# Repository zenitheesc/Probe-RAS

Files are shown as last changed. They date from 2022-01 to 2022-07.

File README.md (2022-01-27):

<h1 align="center" style="color:white; background-color:black">Probe-RAS</h1>
<h4 align="center"> Telecommunication board for the Zenith's Stack architecture.</h4>

<p align="center">
	<a href="http://zenith.eesc.usp.br/">
    
    </a>
    <a href="https://eesc.usp.br/">
    
    </a>
    <a href="https://github.com/zenitheesc/Probe-RAS/blob/main/LICENSE">
    
    </a>
    <a href="https://github.com/zenitheesc/Probe-RAS/issues">
    
    </a>
    <a href="https://github.com/zenitheesc/Probe-RAS/commits/main">
    
    </a>
    <a href="https://github.com/zenitheesc/Probe-RAS/graphs/contributors">
    
    </a>
    <a href="https://github.com/zenitheesc/Probe-RAS/commits/main">
    
    </a>
    <a href="https://github.com/zenitheesc/Probe-RAS/issues">
    
    </a>
    <a href="https://github.com/zenitheesc/Probe-RAS/pulls">
    
    </a>
</p>

<p align="center">
    <a href="#environment-and-tools">Environment and Tools</a> •
    <a href="#Z-Hub">Z-Hub</a> •
    <a href="#Block-Diagram">Block Diagram</a> •
    <a href="#Schematic">Schematic</a> • 
    <a href="#Board">Board</a>
</p>

## Environment and tools

This board was designed using KiCad 5.1.10.

## Block Diagram

<p align = "center">
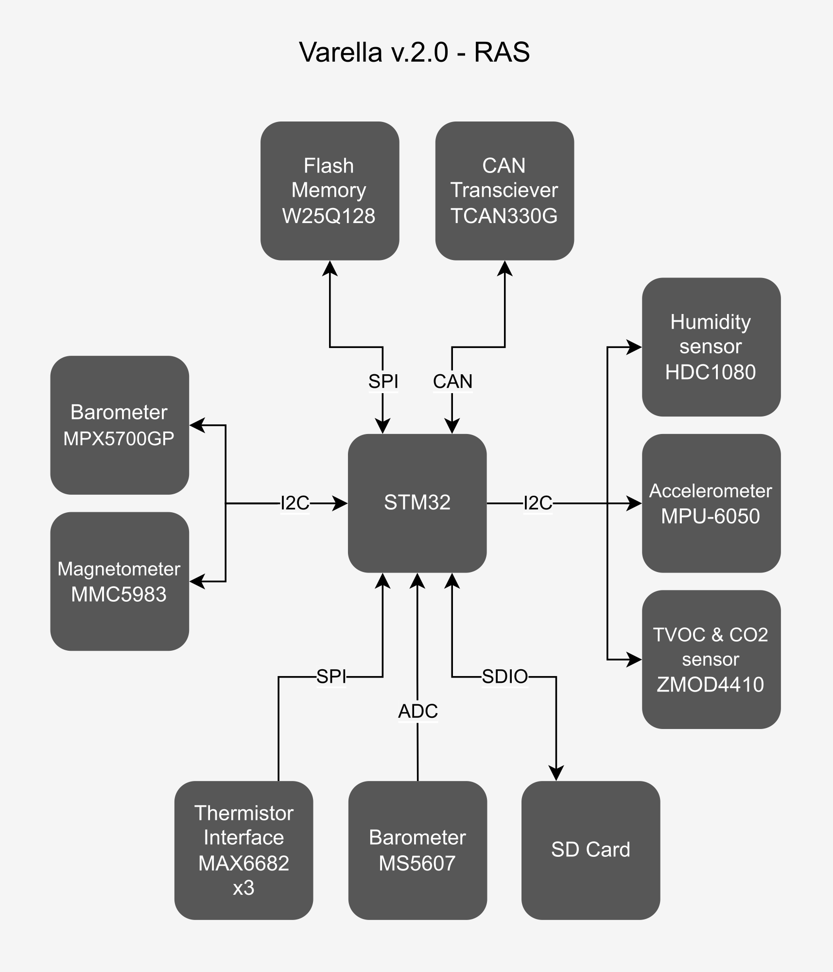
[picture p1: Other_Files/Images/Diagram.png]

</p>

## Z-Hub

This board contains a Stack Connector, with the 2021 Z-Hub pinout.

<table align = "center">
  <thead>
    <tr>
      <th colspan=2>   Z-Hub 2021   </th>
    </tr>
  </thead>
  <tbody>
    <tr>
      <td>GND</td>
      <td>GND</td>
    </tr>
    <tr>
      <td>GND</td>
      <td>GND</td>
    </tr>
    <tr>
      <td>BAT+</td>
      <td>BAT+</td>
    </tr>
    <tr>
      <td>SOl+</td>
      <td>SOl-</td>
    </tr>
    <tr>
      <td>5V</td>
      <td>5V</td>
    </tr>
    <tr>
      <td>3V3</td>
      <td>3V3</td>
    </tr>
    <tr>
      <td>MISO1</td>
      <td>MOSI1</td>
    </tr>
    <tr>
      <td>SCK1</td>
      <td>CAN_H</td>
    </tr>
    <tr>
      <td>SDA </td>
      <td>CAN_L</td>
    </tr>
    <tr>
      <td>SCL</td>
      <td>CE02</td>
    </tr>
    <tr>
      <td>CE11</td>
      <td>CE12</td>
    </tr>
    <tr>
      <td>SDA1</td>
      <td>SCL1</td>
    </tr>
    <tr>
      <td>SDA2</td>
      <td>SCL2</td>
    </tr>
    <tr>
      <td>TX1</td>
      <td>RX1</td>
    </tr>
    <tr>
      <td>TX2</td>
      <td>RX2</td>
    </tr>
    <tr>
      <td>DIG1</td>
      <td>DIG6</td>
    </tr>
    <tr>
      <td>ALRT1</td>
      <td>/CHRG</td>
    </tr>
    <tr>
      <td>PWM</td>
      <td>DIG8</td>
    </tr>
    <tr>
      <td>/FAULT</td>
      <td>DIG9</td>
    </tr>
    <tr>
      <td>DIG5</td>
      <td>DIG10</td>
    </tr>
  </tbody>
</table>

## Schematic

The design was separated in hierarchical sheets to accommodate all components in an orderly way.

The first page contains the STM32L476 with all its accompanying circuits; crystals, debugging LED, Boot solder jumper, decoupling capacitors and reset button. On the same page you find the stack connector along with a programming and debugging connector, as well as the I2C pull-ups for all I2C lines. 

<p align = "center">
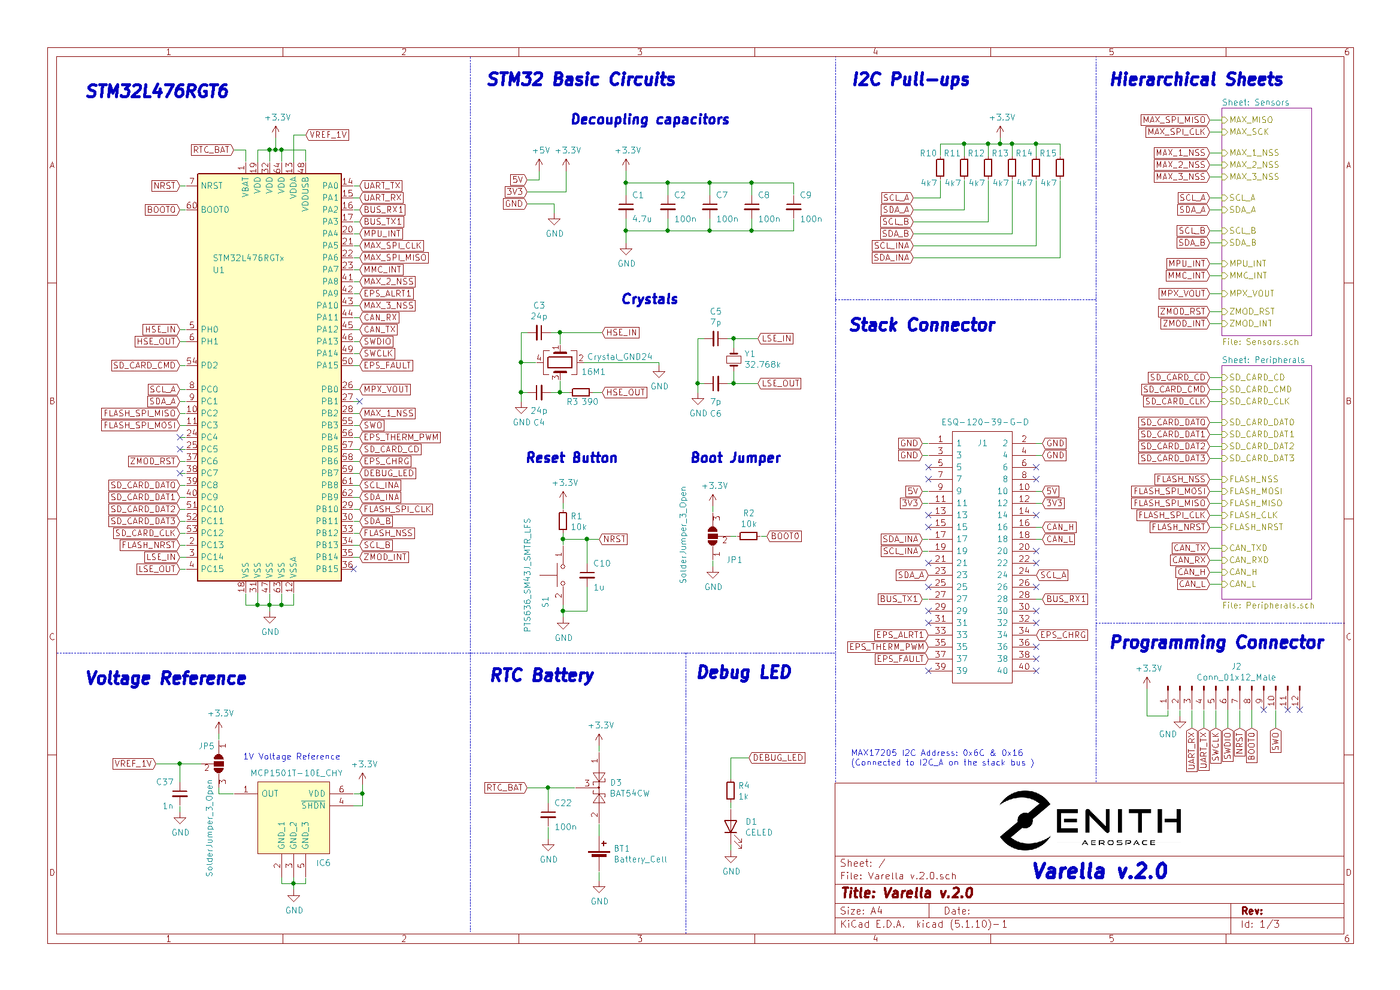
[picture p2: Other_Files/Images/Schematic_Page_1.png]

</p>

The second page contains the basic peripherals, such as the CAN transceiver, the 128 Mb flash memory and the SD card.

<p align = "center">
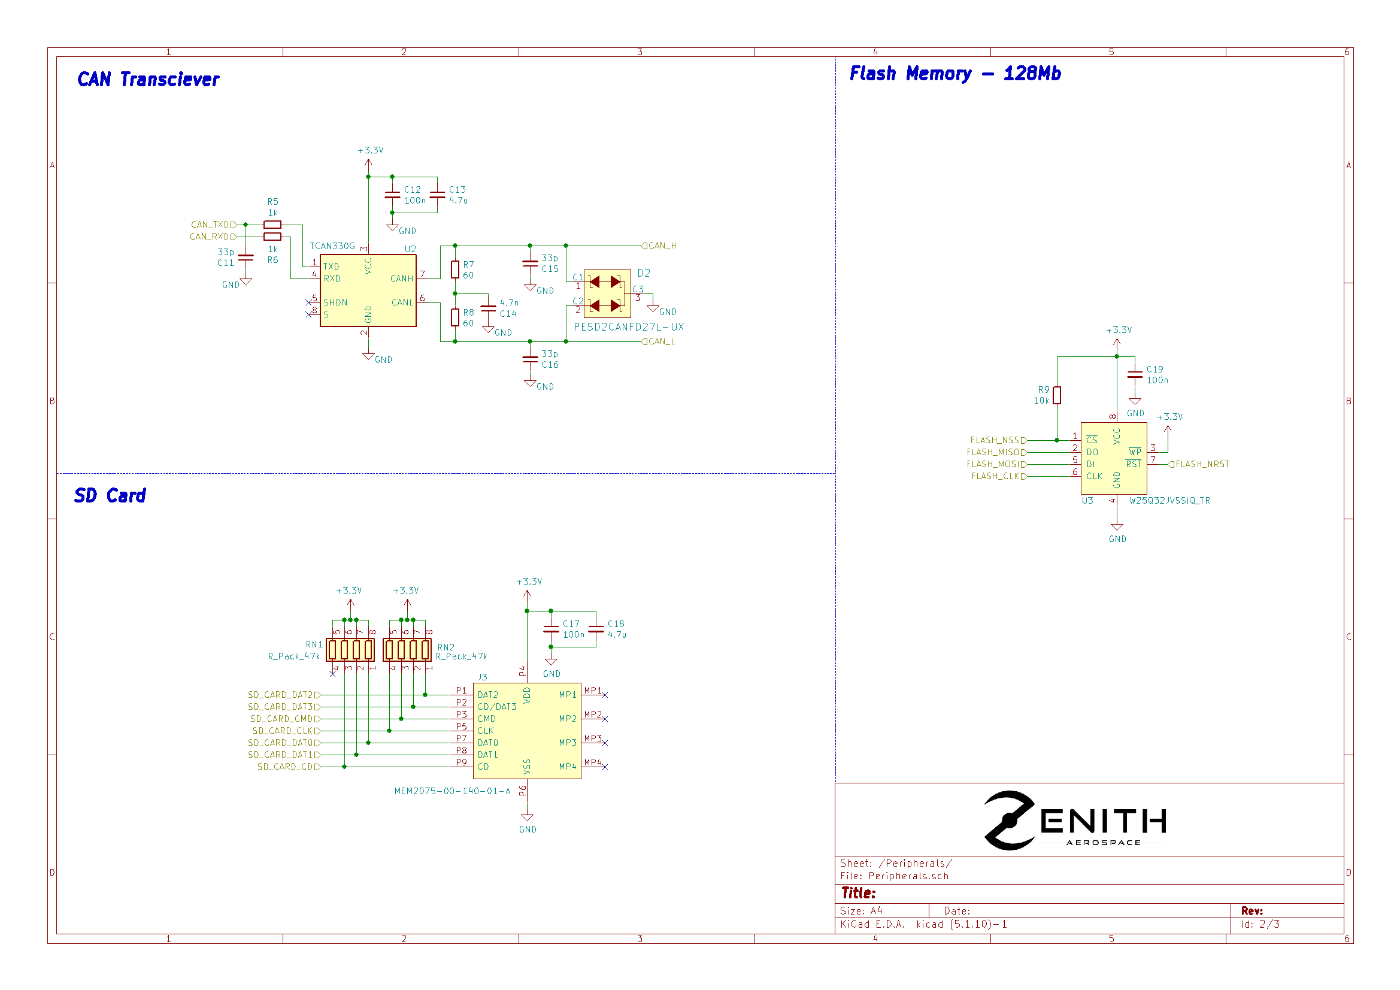
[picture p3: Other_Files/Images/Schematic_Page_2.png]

</p>

The last page contains all the sensors implemented on this board. The I2C ones are divided in two lines, the first one being I2CA, which covers the MS5607 Barometer, the HDC-1080 Humidity sensor and the ZMOD4410 CO2 and air quality sensor. The second I2C line is I2CB, focused on the attitude of the probe, covering the MPU-6050 Accelerometer and the MMC5983 Magnetometer.
This page also contains the Thermistor Interfaces, connected to the STM32 via SPI, but note that these components only use the MISO connection of the SPI line.
The last component that this page contains is the MPX5071GP, which outputs pressure data via a 5V line, read via an ADC by the STM32.

<p align = "center">
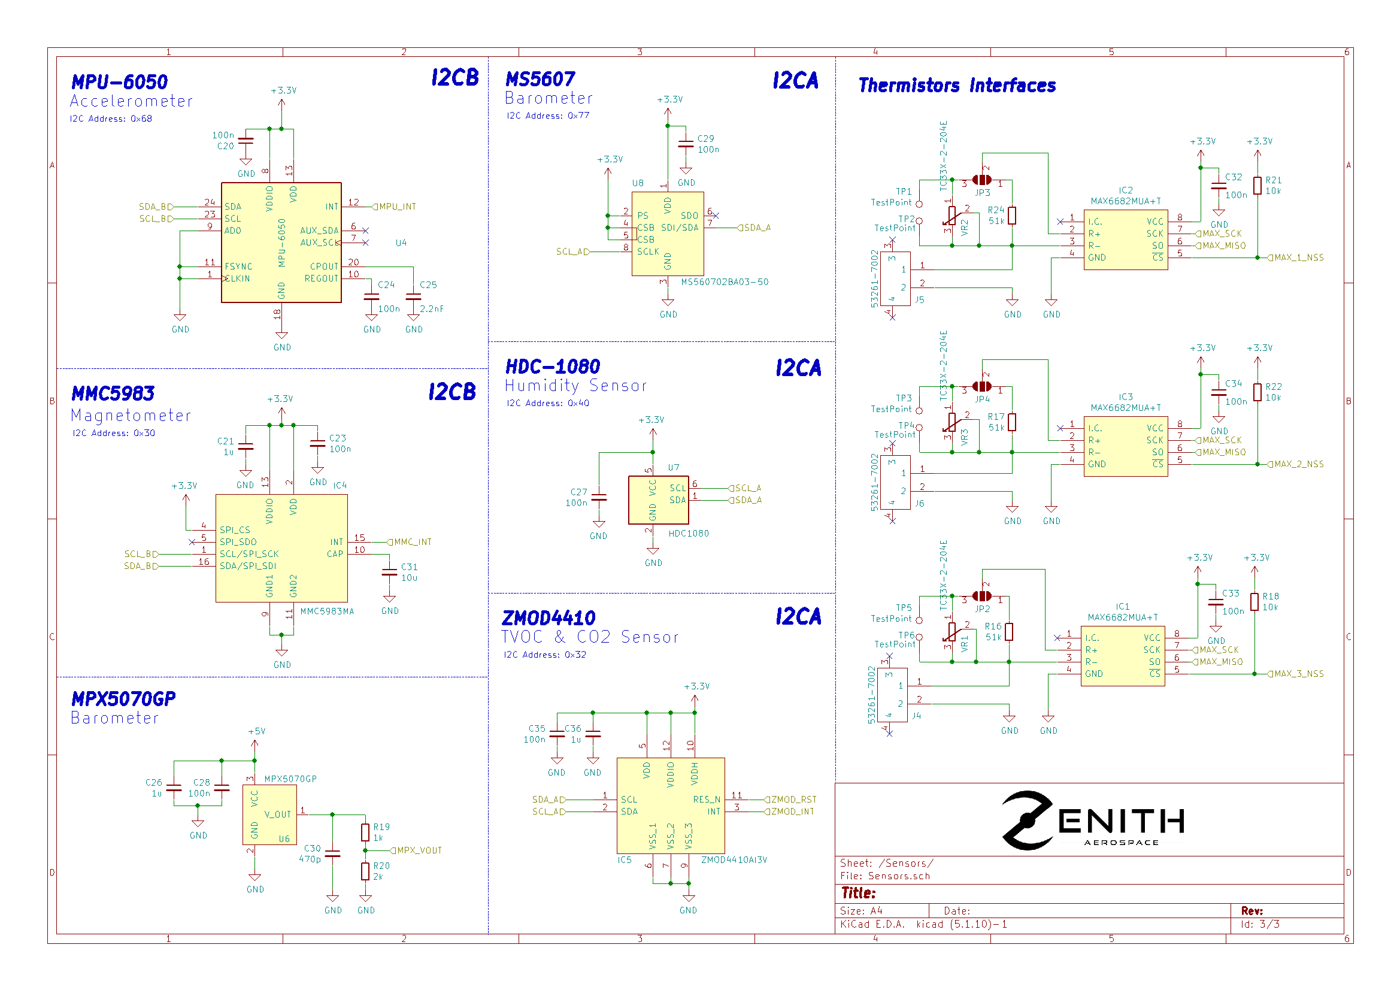
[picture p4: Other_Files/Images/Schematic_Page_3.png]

</p>

## Board

<p align = "center">
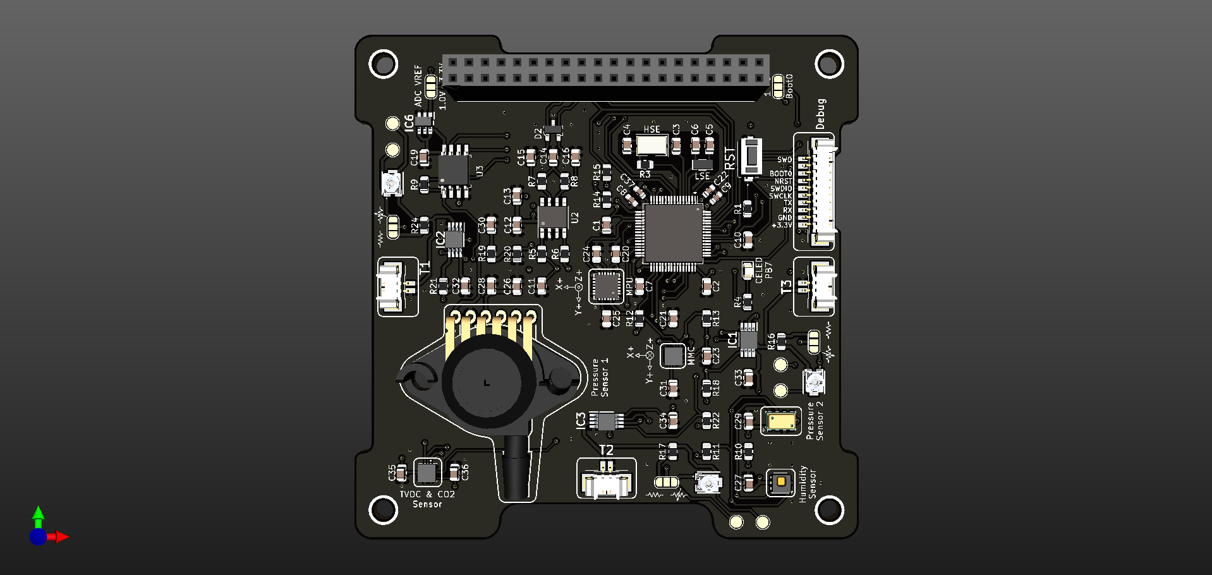
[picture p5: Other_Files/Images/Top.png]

</p>

<p align = "center">
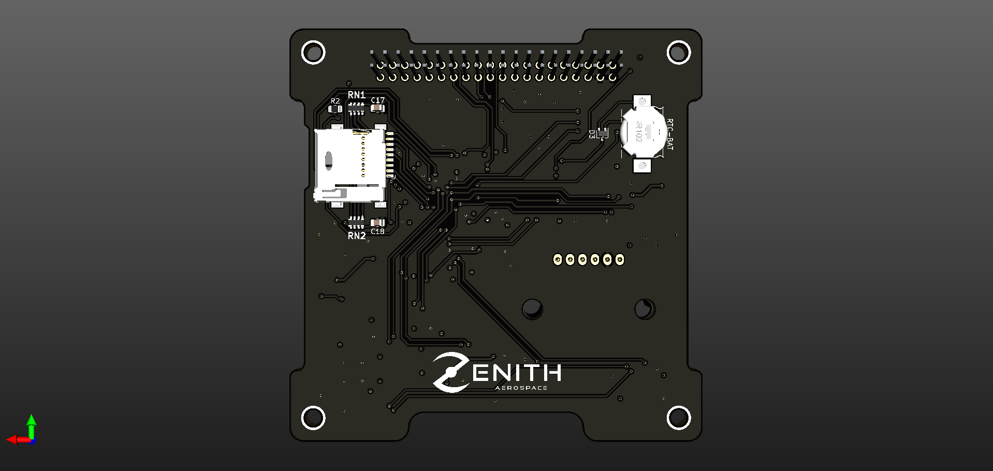
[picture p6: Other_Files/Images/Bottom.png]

</p>

<p align = "center">
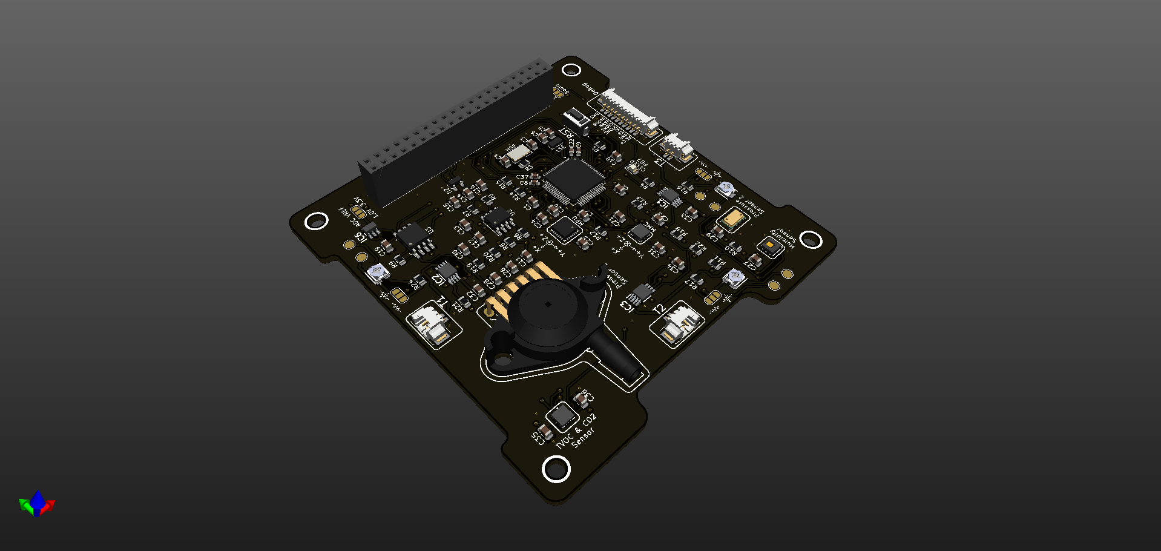
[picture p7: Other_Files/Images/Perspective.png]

</p>

---

<p align="center">
    <a href="http://zenith.eesc.usp.br">
    
    </a> 
    <a href="https://www.facebook.com/zenitheesc">
    
    </a> 
    <a href="https://www.instagram.com/zenith_eesc/">
    
    </a>

</p>
<p align = "center">
<a href="zenith.eesc@gmail.com">zenith.eesc@gmail.com</a>
</p>

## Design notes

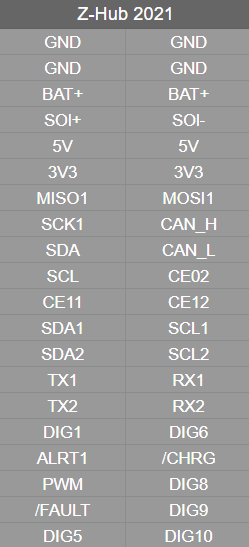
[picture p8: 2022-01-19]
Other_Files/Images/Z-Hub.png

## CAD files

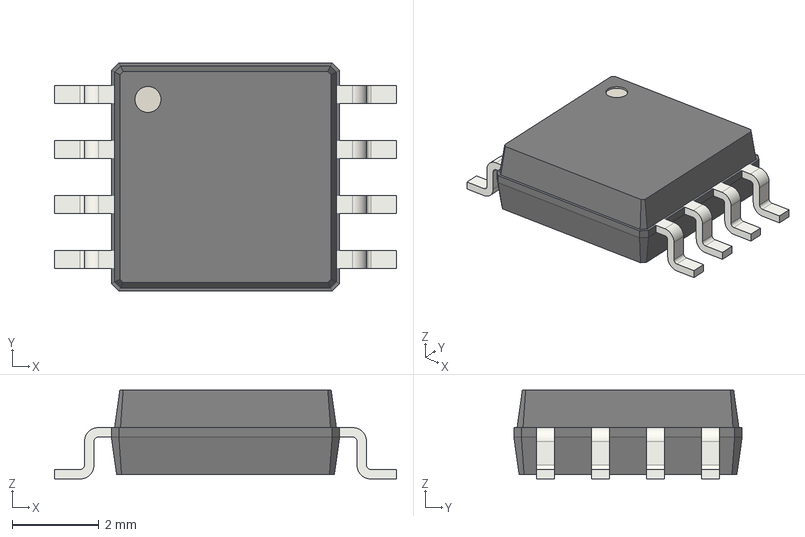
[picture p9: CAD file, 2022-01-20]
KiCad_Files/shapes3D/SOIC-8_5.275x5.275mm_P1.27mm.step
7.90 x 5.28 x 2.06 mm

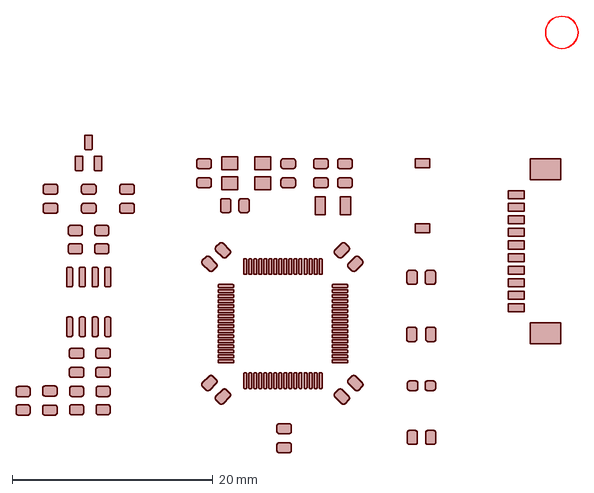
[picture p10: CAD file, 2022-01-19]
KiCad_Files/TopLayerComponents.dxf
55.9 x 43.4 mm

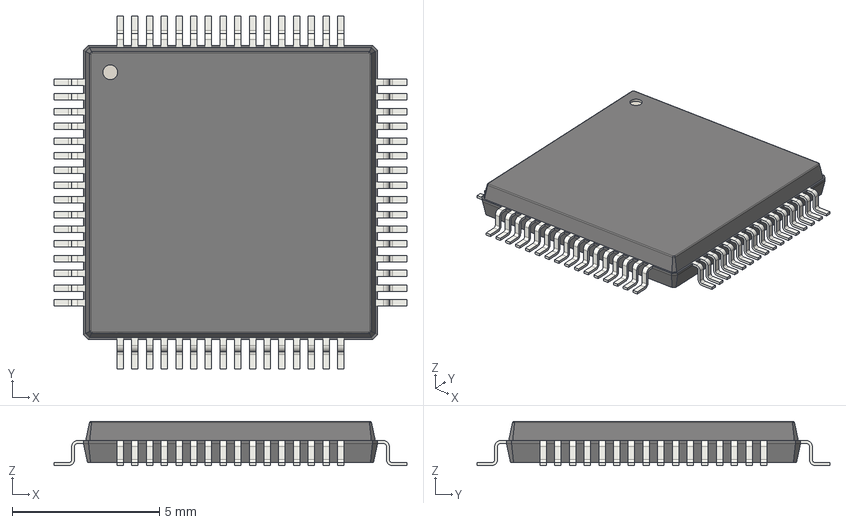
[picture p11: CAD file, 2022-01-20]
KiCad_Files/shapes3D/LQFP-64_10x10mm_P0.5mm.step
12.0 x 12.0 x 1.50 mm

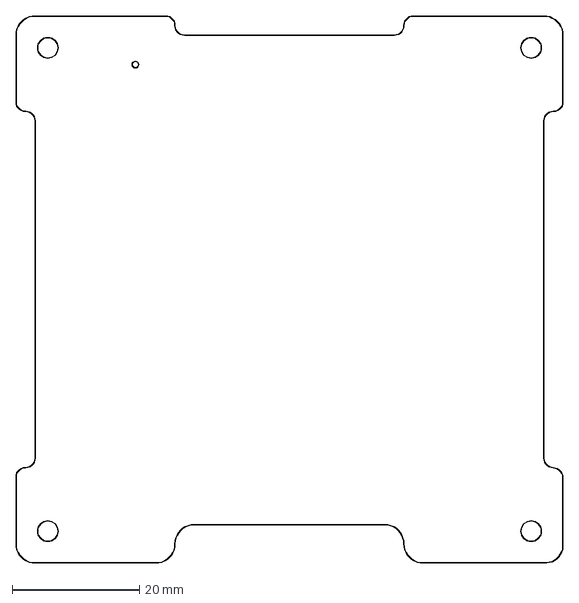
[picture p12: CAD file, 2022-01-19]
KiCad_Files/Stack Model.dxf
86.0 x 86.0 mm

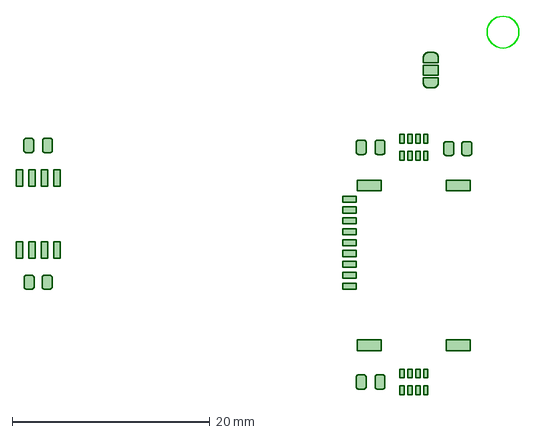
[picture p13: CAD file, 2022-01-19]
KiCad_Files/BottomLayerComponents.dxf
50.9 x 38.3 mm

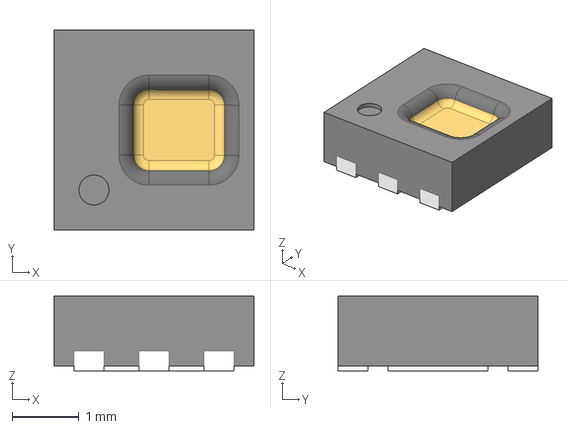
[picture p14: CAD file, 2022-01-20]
KiCad_Files/shapes3D/HDC-1080.step
3.00 x 3.00 x 1.12 mm

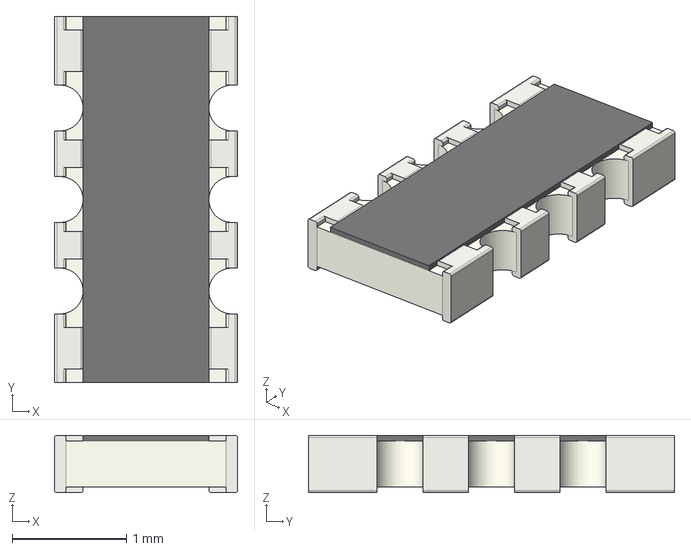
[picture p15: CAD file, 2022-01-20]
KiCad_Files/shapes3D/R_Array_Convex_4x0603.step
1.60 x 3.20 x 0.5 mm

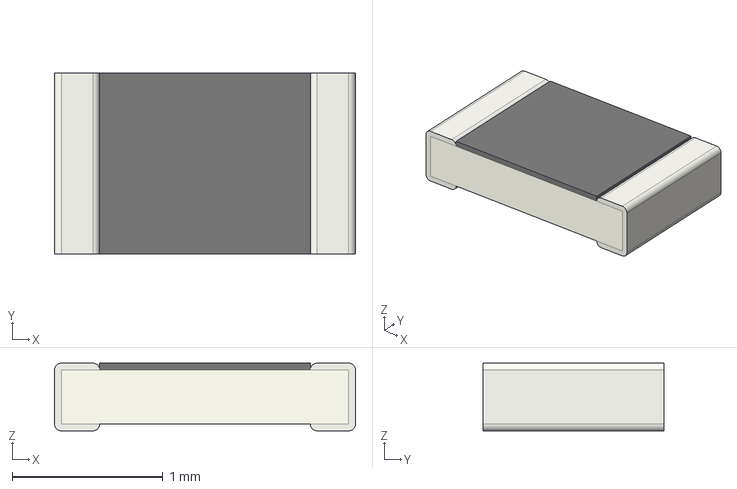
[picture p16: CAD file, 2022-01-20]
KiCad_Files/shapes3D/R_0805_2012Metric.step
2.00 x 1.20 x 0.45 mm

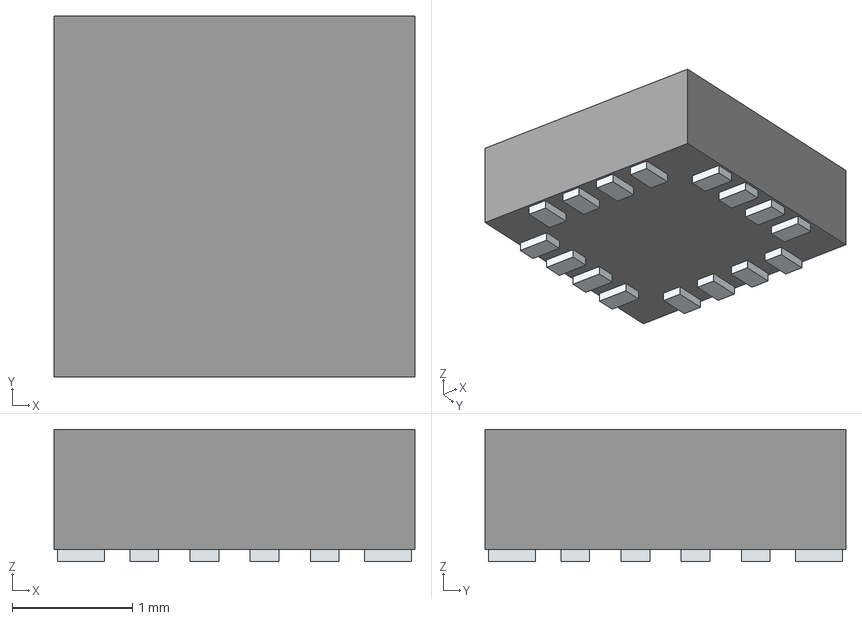
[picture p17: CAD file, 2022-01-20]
KiCad_Files/shapes3D/MMC5983MA.stp
3.00 x 3.00 x 1.10 mm
Pins

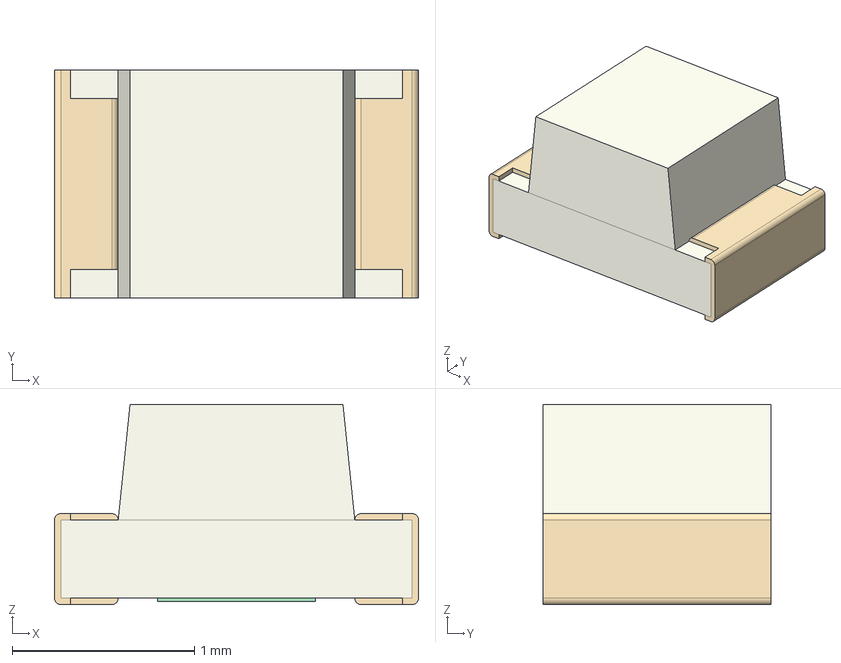
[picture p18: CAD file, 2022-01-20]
KiCad_Files/shapes3D/LED_0805_2012Metric.step
2.00 x 1.25 x 1.10 mm

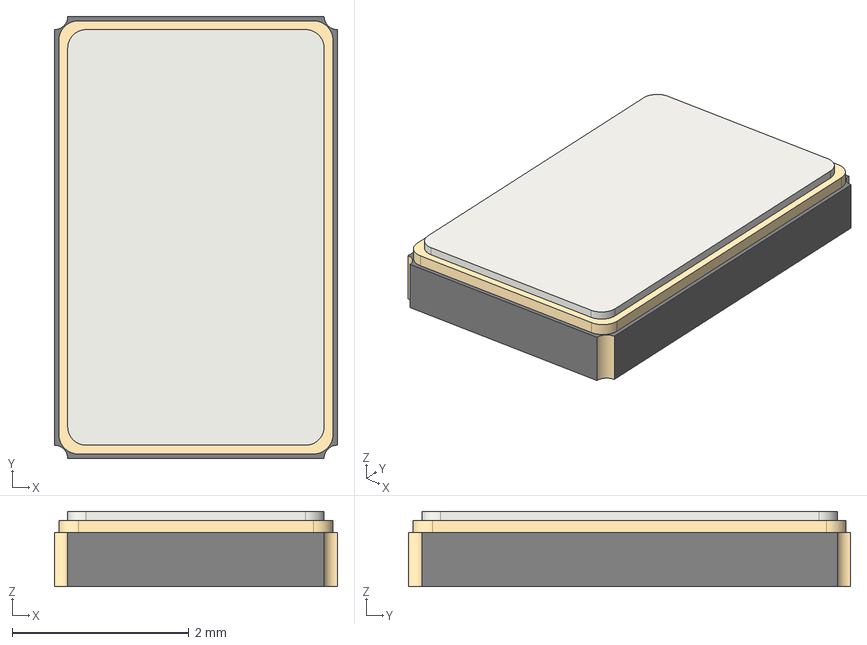
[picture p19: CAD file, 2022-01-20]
KiCad_Files/shapes3D/Crystal_SMD_4Pin_5x3.2mm.step
3.20 x 5.00 x 0.85 mm

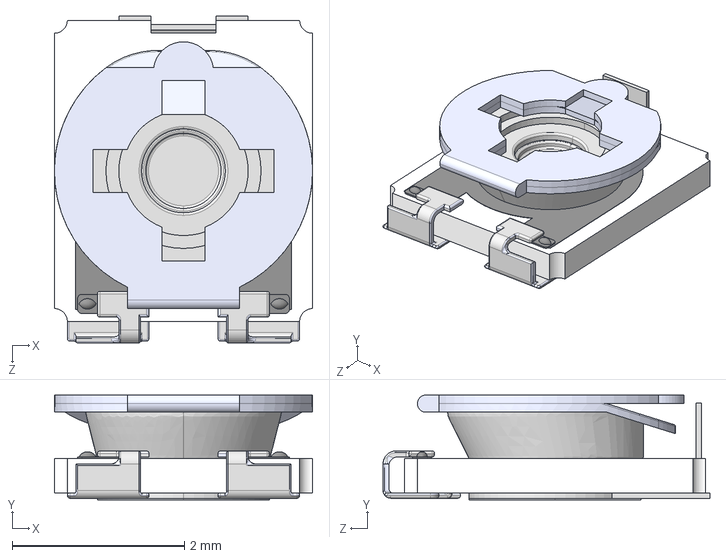
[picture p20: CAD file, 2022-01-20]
KiCad_Files/shapes3D/TC33X-2-204E.stp
3.00 x 1.22 x 3.80 mm

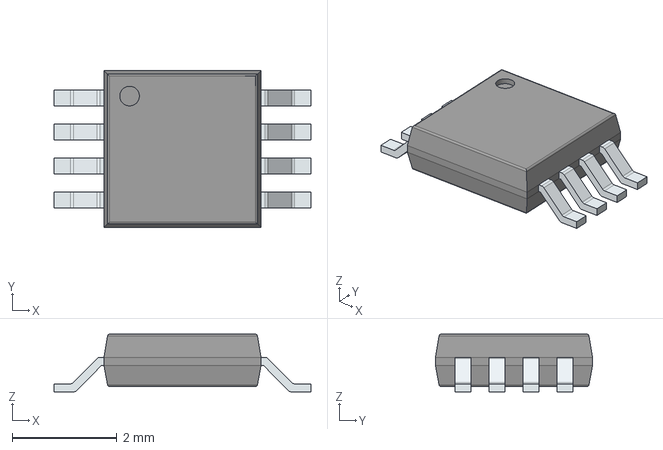
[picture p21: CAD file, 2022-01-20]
KiCad_Files/shapes3D/MAX6682MUA+T.stp
4.91 x 3.00 x 1.10 mm
PinsArrayLR

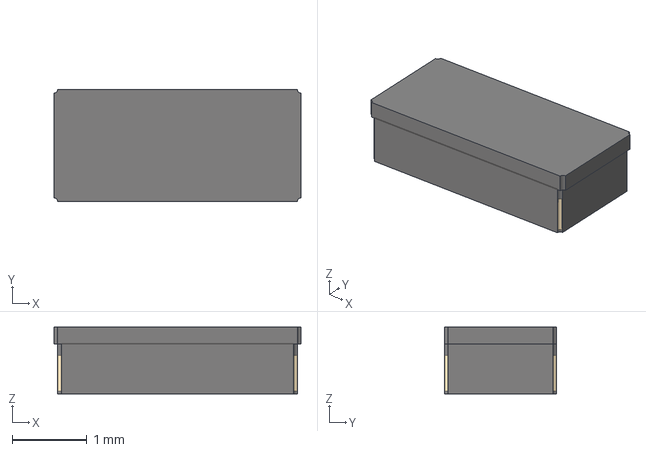
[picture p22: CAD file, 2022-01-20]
KiCad_Files/shapes3D/Crystal_SMD_MicroCrystal_CC7V-T1A-2Pin_3.2x1.5mm.step
3.30 x 1.50 x 0.89 mm

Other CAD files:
KiCad_Files/shapes3D/SOT-23.step
KiCad_Files/shapes3D/C_0805_2012Metric.step
KiCad_Files/shapes3D/User Library-MPX5100GP.step
KiCad_Files/shapes3D/QFN-24-1EP_4x4mm_P0.5mm_EP2.7x2.6mm.step
KiCad_Files/shapes3D/532610271 recolored.step
KiCad_Files/shapes3D/532611071 recolored.step
KiCad_Files/shapes3D/M20-6102045.stp
KiCad_Files/shapes3D/MEM2075-00-140-01-A.stp
KiCad_Files/shapes3D/MS560702BA03-50.step
KiCad_Files/shapes3D/PTS636_SM43J_SMTR_LFS.stp
KiCad_Files/shapes3D/SOIC-8_3.9x4.9mm_P1.27mm.step
KiCad_Files/shapes3D/ZMOD4410AI3V.stp

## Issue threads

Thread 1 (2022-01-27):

Cobertura útil do

leocelente, 2022-01-27:
A expectativa é que a sonda inicie em: [0...30] ± 1 km
Segundo o [modelo atmosférico da NASA](https://www.grc.nasa.gov/WWW/K-12/airplane/atmosmet.html), podemos calcular a pressão em função da altitude:

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

Que são 12hPa

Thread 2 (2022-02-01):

Mecanismo de Configuração

leocelente, 2022-02-01:
# Configuração
## Especificação

Dada uma lista de configurações, construir funções para gerenciar 64-bits de configuração do sistema.
### Tipos
```c
typedef enum { X, Y ... } config_names_t;
typedef enum { CONFIG0, CONFIG1} X_config_t;
//...
typedef struct {
    X_config_t X : 1; // configuração com 2 opções (cabe em 1 bit)
    Y_config_t Y : 3;
    // ...
} config_values_t;

typedef union {
    config_values_t values;
    uint8_t raw[8];
} config_reg_t;
```
### Funções
As configurações variam entre cada sistema, mas ambos são 8 bytes (64-bits). Para conveniência do resto do sistema, deve ser criada também algumas funções para manipular.
```c
/**
   Configura um valor
*/
int config_set_value(config_reg_t *reg, config_names_t config, int value);
int config_reset(config_reg_t *reg);
int config_init(config_reg_t *reg);
int config_set_raw(config_reg_t *reg, uint8_t const *data);
int config_get_value(config_reg_t *reg, config_names_t config);
int config_get_raw(config_reg_t *reg, uint8_t *data);
```

O uso de ints nos argumentos é porque qualquer `enum` é por baixo dos panos um ´int`, então qualquer um dos tipos de configuração pode ser passado. Não tenho certeza se essa é a melhor forma de implementar, se pensar em alguma coisa
sinta-se a vontade.

As funções terminando em `_value` se aplicam a apenas um dos valores, enquanto as que terminam em `_raw`, mudam todos de uma vez.

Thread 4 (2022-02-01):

Mecanismo de Armazenamento

leocelente, 2022-02-01:
Implementar as structs e funções para escrever os dados da RAS e CDH
```c
typedef struct {
  float altiude ;
  uint8_t tempo;
  // ...
} dados_t;

union {
   dados_t valores;
   uint8_t bytes[sizeof(dados_t)];
} pacote_t;

int write_flash(pacote_t pacote){
   // escreve num txt os bytes
}

int write_sdcard(pacote_t pacote){
   // escreve num txt os valores em string (csv)
}
```

## Resultado Esperado
Ter um arquivo txt com o CSV dos dados  como iriam para o cartão SD.  E outro arquivo `.bin` ou `.txt` com os bytes em string

leocelente, 2022-02-01:
lembramos que tem dois tipos de pacote para RAS, que serão armazenados de forma independete o geral e da IMU (grupo1 e grupo2)

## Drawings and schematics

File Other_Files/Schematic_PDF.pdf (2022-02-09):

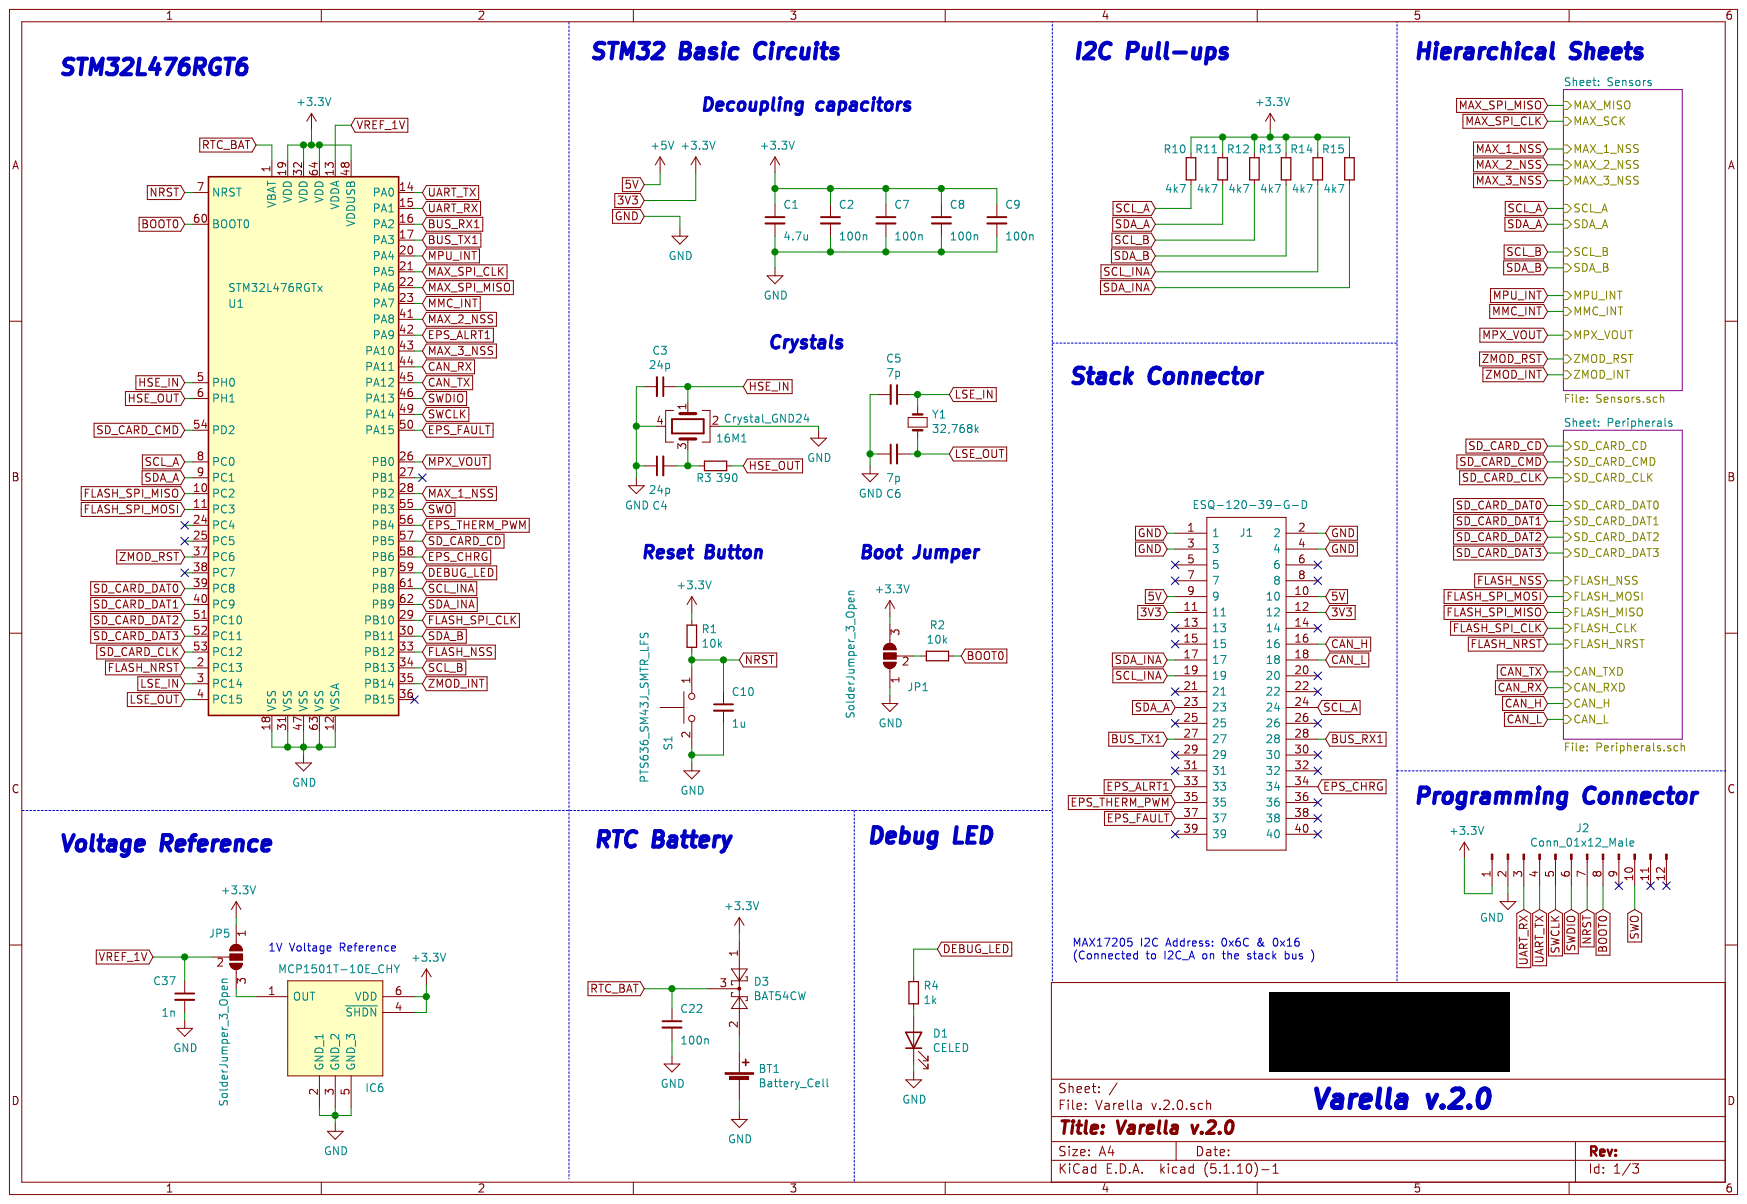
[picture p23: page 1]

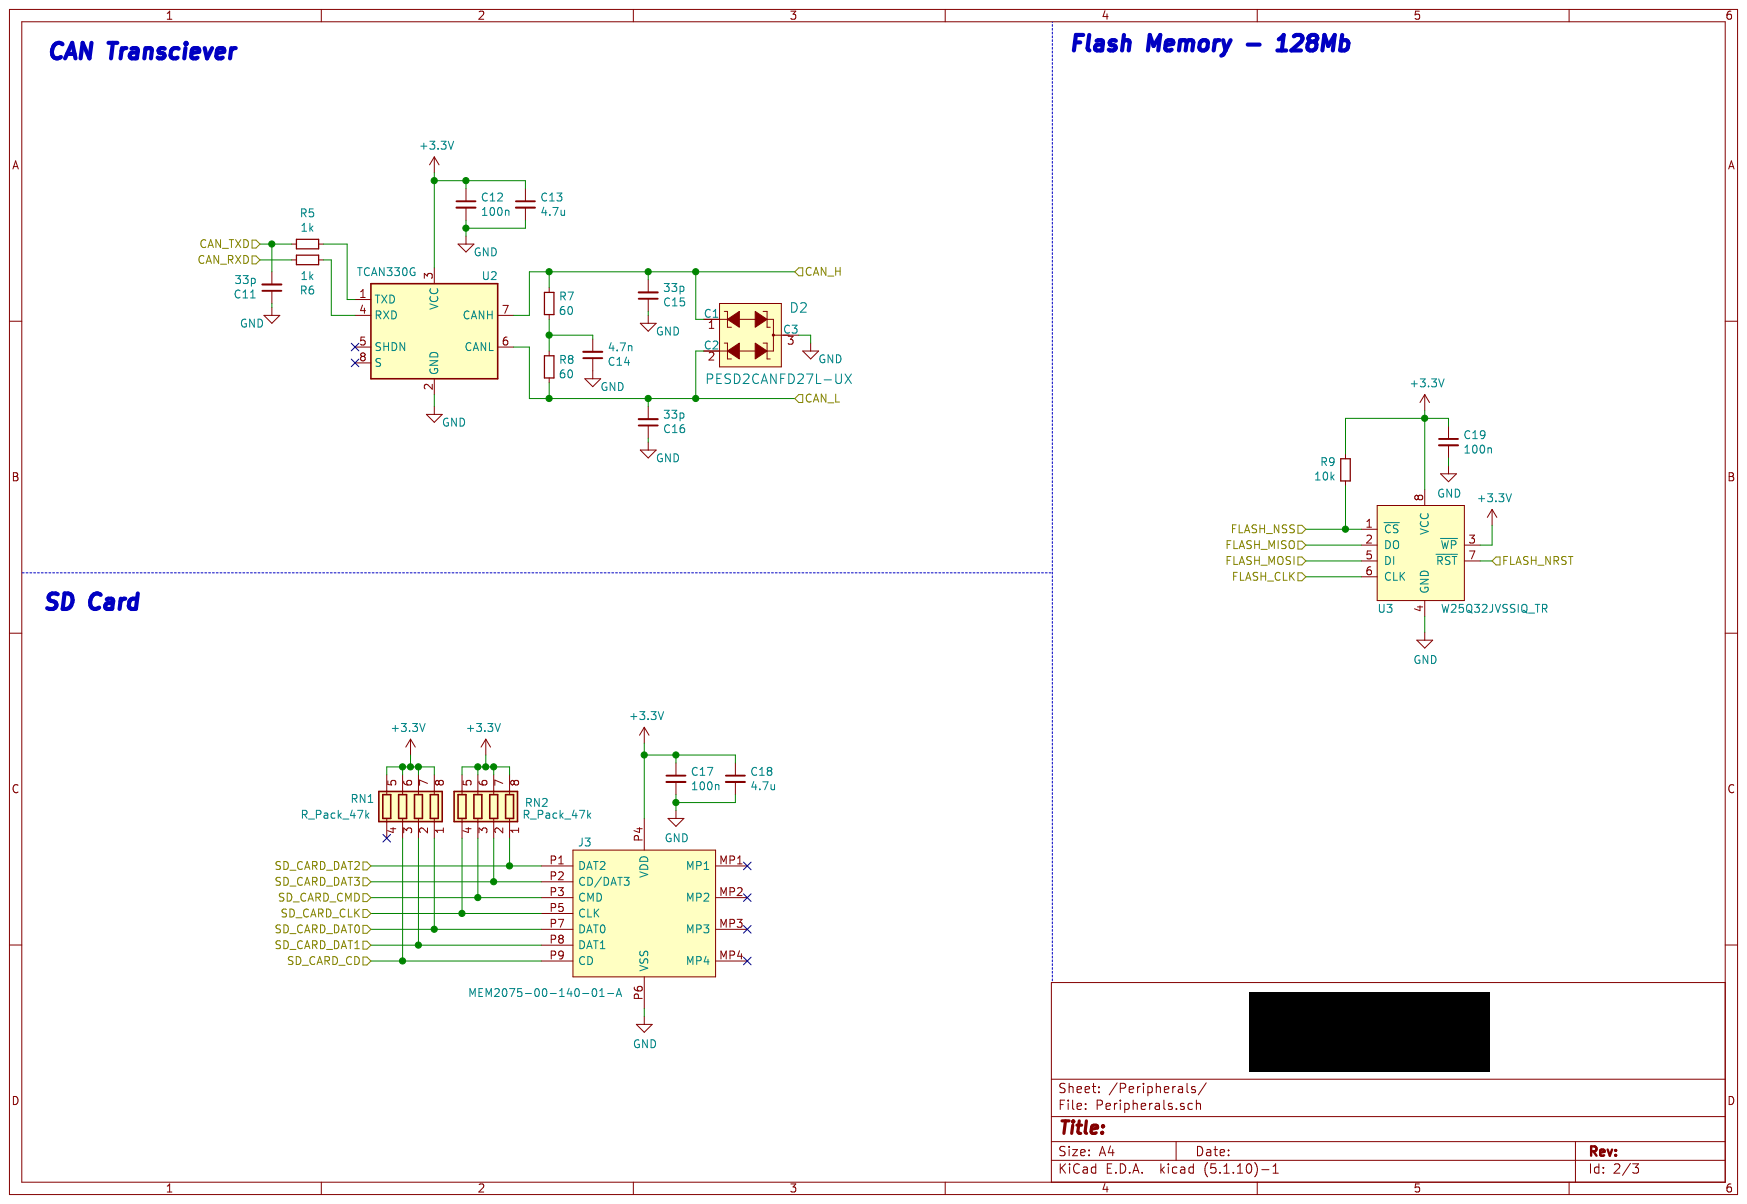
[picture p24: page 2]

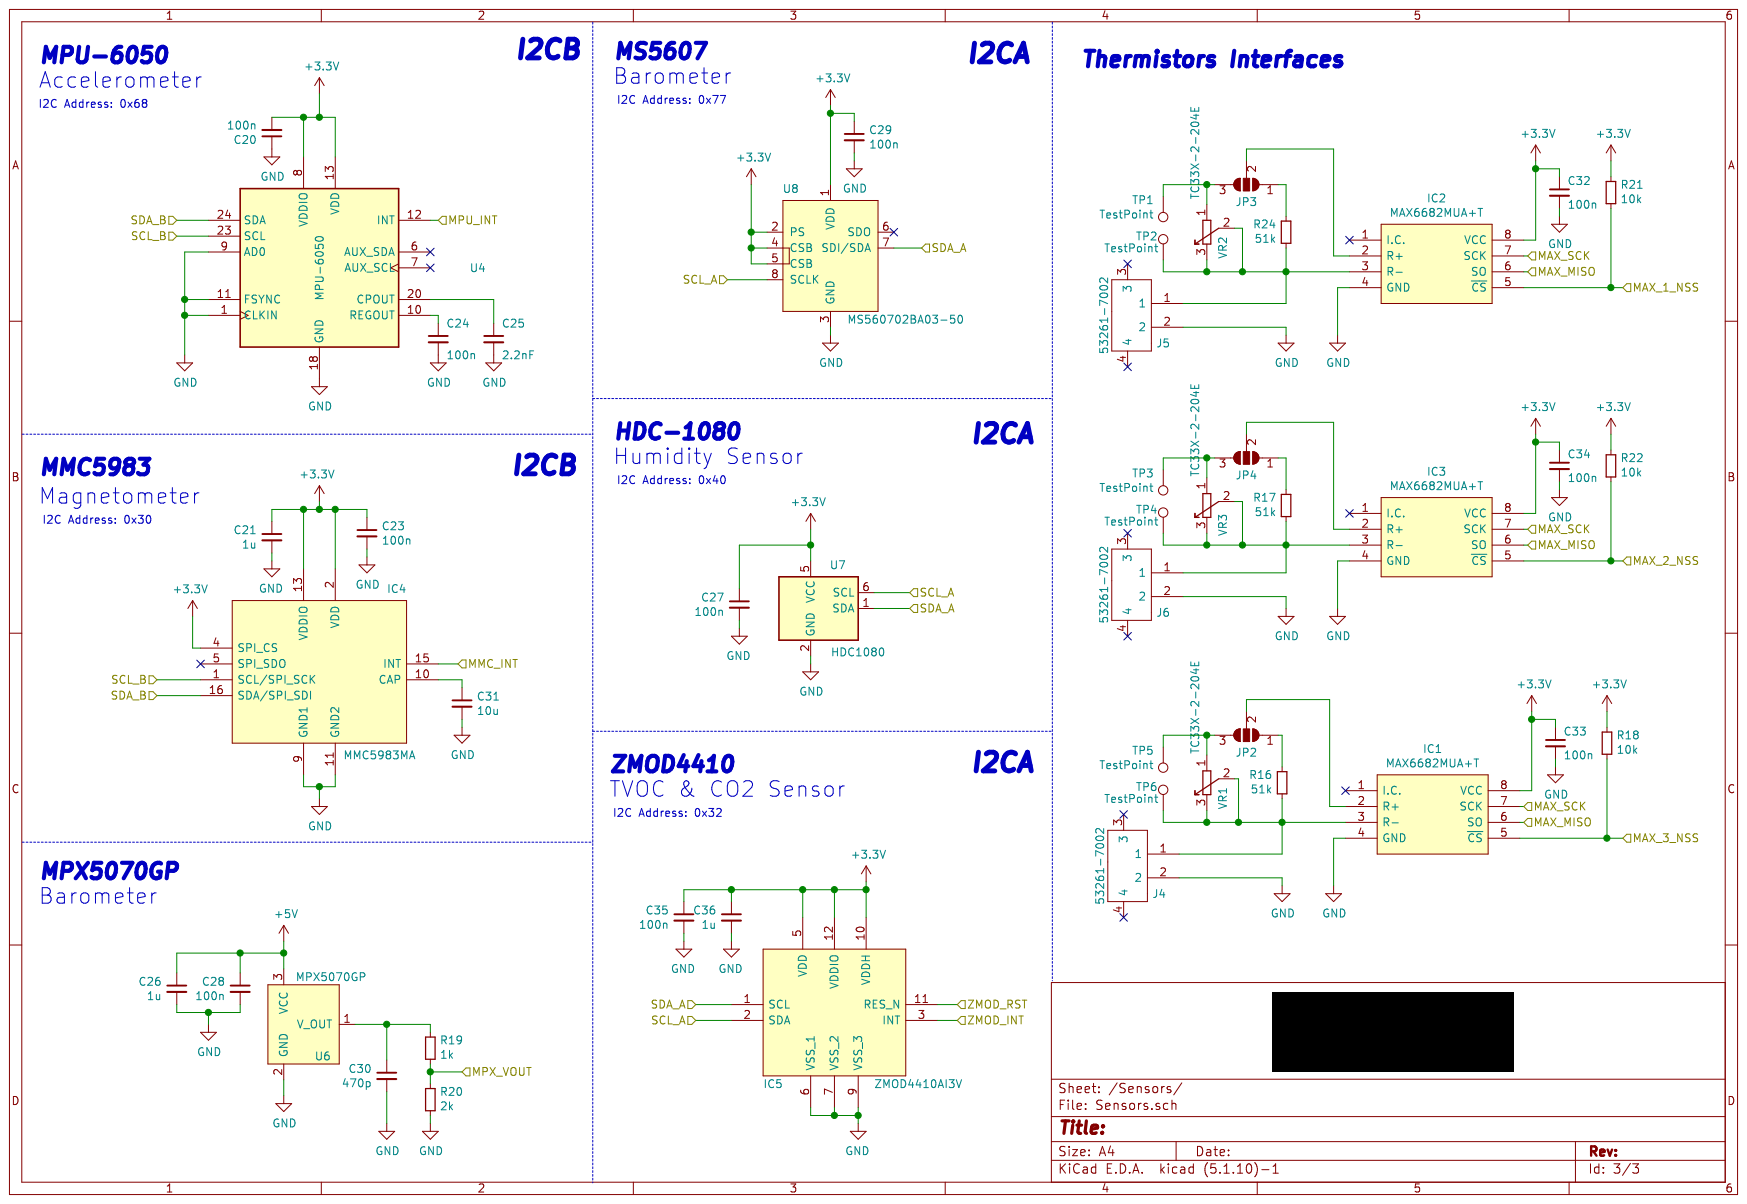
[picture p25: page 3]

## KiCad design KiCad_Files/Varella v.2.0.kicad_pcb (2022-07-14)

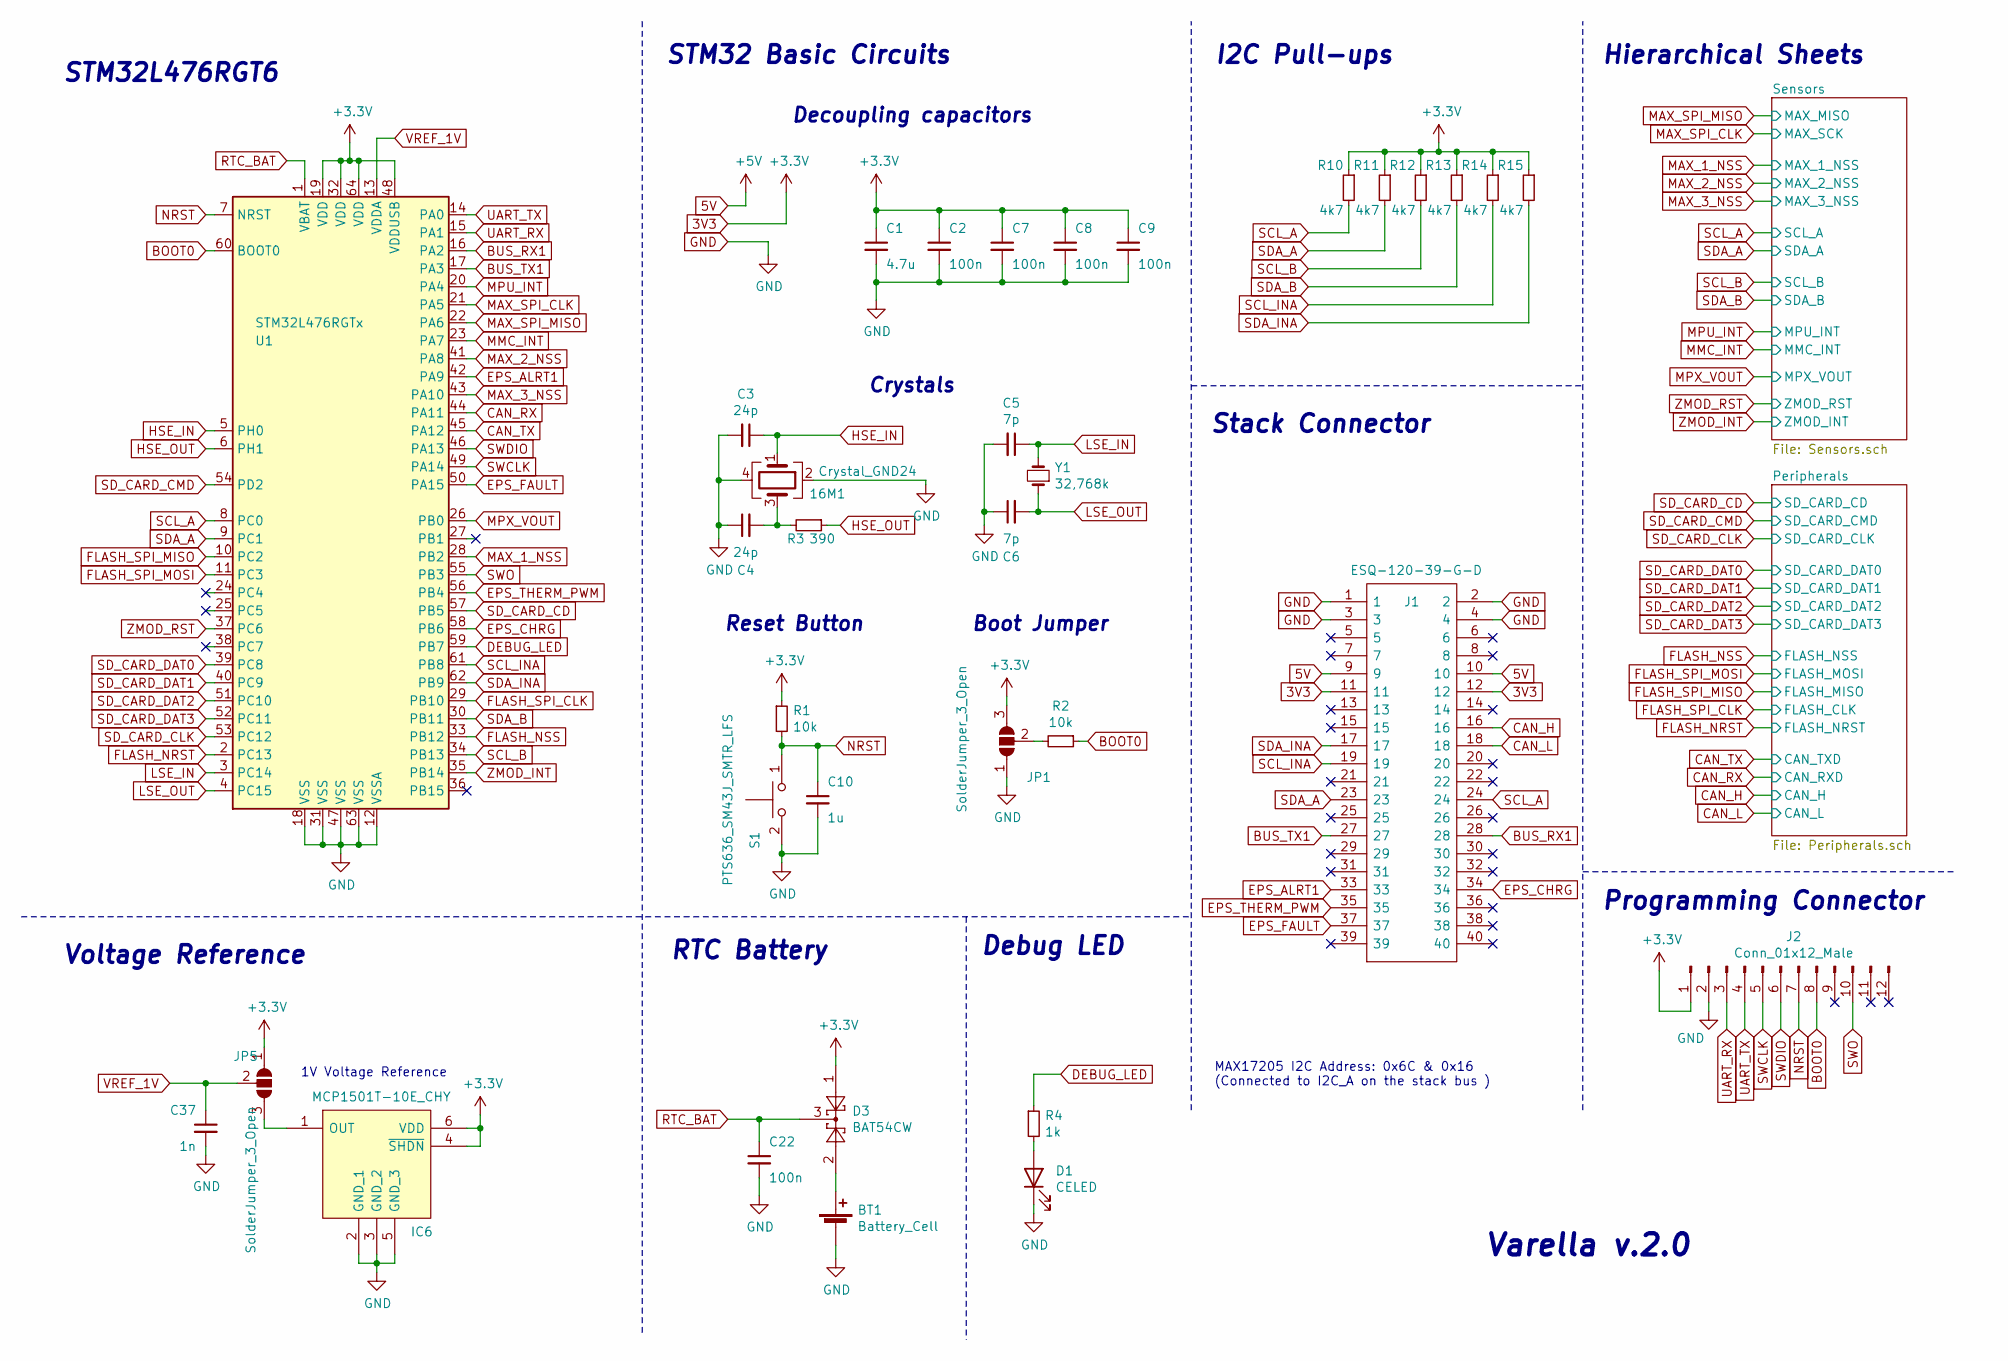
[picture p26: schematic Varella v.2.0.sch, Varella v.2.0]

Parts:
16M1: Crystal_GND24; Crystal_SMD_5032-4Pin_5.0x3.2mm_Hand_Soldering
BT1: Battery_Cell; 3030
C1: 4.7u; C_0805_2012Metric
C2, C7: 100n; C_0805_2012Metric
C3, C4: 24p; C_0805_2012Metric
C5, C6: 7p; C_0805_2012Metric
C8, C9, C22: 100n; C_0603_1608Metric
C10: 1u; C_0805_2012Metric
C37: 1n; C_0603_1608Metric
D1: CELED; LED_0805_2012Metric
D3: BAT54CW; SOT-323_SC-70
IC6: MCP1501T-10E_CHY; SOT95P280X145-6N; Mouser Part Number 579-MCP1501T-10E/CHY
J1: ESQ-120-39-G-D; ESQ-120-Y-X-D; Mouser Part Number 200-ESQ12039GD
J2: Conn_01x12_Male; 532611071
JP1, JP5: SolderJumper_3_Open; SolderJumper-3_P1.3mm_Open_RoundedPad1.0x1.5mm_NumberLabels
R1, R2: 10k; R_0805_2012Metric
R3: 390; R_0805_2012Metric
R4: 1k; R_0805_2012Metric
R10, R11, R12, R13, R14, R15: 4k7; R_0805_2012Metric
S1: PTS636_SM43J_SMTR_LFS; PTS636SM43JSMTRLFS; Mouser Part Number 611-PTS636SM43JSMTRL
U1: STM32L476RGTx; LQFP-64_10x10mm_P0.5mm
Y1: 32,768k; Crystal_SMD_3215-2Pin_3.2x1.5mm

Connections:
3V3: C1.1, C2.1, C7.1, C8.1, C9.1, D3.1, IC6.4 (~SHDN), IC6.6 (VDD), J1.11, J1.12, J2.1, JP1.3 (B), JP5.1 (A), R1.1, R10.1, R11.1, R12.1, R13.1, R14.1, R15.1, U1.19 (VDD), U1.32 (VDD), U1.48 (VDDUSB), U1.64 (VDD); also elsewhere on the board
5V: J1.9, J1.10; also elsewhere on the board
BOOT0: J2.8, R2.1, U1.60 (BOOT0)
BUS_RX1: J1.28, U1.16 (PA2)
BUS_TX1: J1.27, U1.17 (PA3)
CAN_H: J1.16; also elsewhere on the board
CAN_L: J1.18; also elsewhere on the board
CAN_RX: U1.44 (PA11); also elsewhere on the board
CAN_TX: U1.45 (PA12); also elsewhere on the board
DEBUG_LED: R4.1, U1.59 (PB7)
EPS_ALRT1: J1.33, U1.42 (PA9)
EPS_CHRG: J1.34, U1.58 (PB6)
EPS_FAULT: J1.37, U1.50 (PA15)
EPS_THERM_PWM: J1.35, U1.56 (PB4)
FLASH_NRST: U1.2 (PC13); also elsewhere on the board
FLASH_NSS: U1.33 (PB12); also elsewhere on the board
FLASH_SPI_CLK: U1.29 (PB10); also elsewhere on the board
FLASH_SPI_MISO: U1.10 (PC2); also elsewhere on the board
FLASH_SPI_MOSI: U1.11 (PC3); also elsewhere on the board
GND: 16M1.2, 16M1.4, BT1.2 (-), C1.2, C2.2, C3.2, C4.1, C5.2, C6.1, C7.2, C8.2, C9.2, C10.2, C22.2, C37.2, D1.1 (K), IC6.2 (GND_1), IC6.3 (GND_2), IC6.5 (GND_3), J1.1, J1.2, J1.3, J1.4, J2.2, JP1.1 (A), S1.2, U1.12 (VSSA), U1.18 (VSS), U1.31 (VSS), U1.47 (VSS), U1.63 (VSS); also elsewhere on the board
HSE_IN: 16M1.1, C3.1, U1.5 (PH0)
HSE_OUT: R3.1, U1.6 (PH1)
LSE_IN: C5.1, U1.3 (PC14), Y1.2
LSE_OUT: C6.2, U1.4 (PC15), Y1.1
MAX_1_NSS: U1.28 (PB2); also elsewhere on the board
MAX_2_NSS: U1.41 (PA8); also elsewhere on the board
MAX_3_NSS: U1.43 (PA10); also elsewhere on the board
MAX_SPI_CLK: U1.21 (PA5); also elsewhere on the board
MAX_SPI_MISO: U1.22 (PA6); also elsewhere on the board
MMC_INT: U1.23 (PA7); also elsewhere on the board
MPU_INT: U1.20 (PA4); also elsewhere on the board
MPX_VOUT: U1.26 (PB0); also elsewhere on the board
NRST: C10.1, J2.7, R1.2, S1.1, U1.7 (NRST)
unnamed: 16M1.3, C4.2, R3.2
unnamed: BT1.1 (+), D3.2
unnamed: D1.2 (A), R4.2
unnamed: IC6.1 (OUT), JP5.3 (B)
unnamed: JP1.2 (C), R2.2
RTC_BAT: C22.1, D3.3, U1.1 (VBAT)
SCL_A: J1.24, R10.2, U1.8 (PC0); also elsewhere on the board
SCL_B: R12.2, U1.34 (PB13); also elsewhere on the board
SCL_INA: J1.19, R14.2, U1.61 (PB8)
SDA_A: J1.23, R11.2, U1.9 (PC1); also elsewhere on the board
SDA_B: R13.2, U1.30 (PB11); also elsewhere on the board
SDA_INA: J1.17, R15.2, U1.62 (PB9)
SD_CARD_CD: U1.57 (PB5); also elsewhere on the board
SD_CARD_CLK: U1.53 (PC12); also elsewhere on the board
SD_CARD_CMD: U1.54 (PD2); also elsewhere on the board
SD_CARD_DAT0: U1.39 (PC8); also elsewhere on the board
SD_CARD_DAT1: U1.40 (PC9); also elsewhere on the board
SD_CARD_DAT2: U1.51 (PC10); also elsewhere on the board
SD_CARD_DAT3: U1.52 (PC11); also elsewhere on the board
SWCLK: J2.5, U1.49 (PA14)
SWDIO: J2.6, U1.46 (PA13)
SWO: J2.10, U1.55 (PB3)
UART_RX: J2.3, U1.15 (PA1)
UART_TX: J2.4, U1.14 (PA0)
VREF_1V: C37.1, JP5.2 (C), U1.13 (VDDA)
ZMOD_INT: U1.35 (PB14); also elsewhere on the board
ZMOD_RST: U1.37 (PC6); also elsewhere on the board

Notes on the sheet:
Programming Connector
Stack Connector
Hierarchical Sheets
Varella v.2.0
STM32L476RGT6
I2C Pull-ups
MAX17205 I2C Address: 0x6C & 0x16 (Connected to I2C_A on the stack bus )
1V Voltage Reference
Voltage Reference
RTC Battery
Debug LED
STM32 Basic Circuits
Crystals
Decoupling capacitors
Reset Button
Boot Jumper

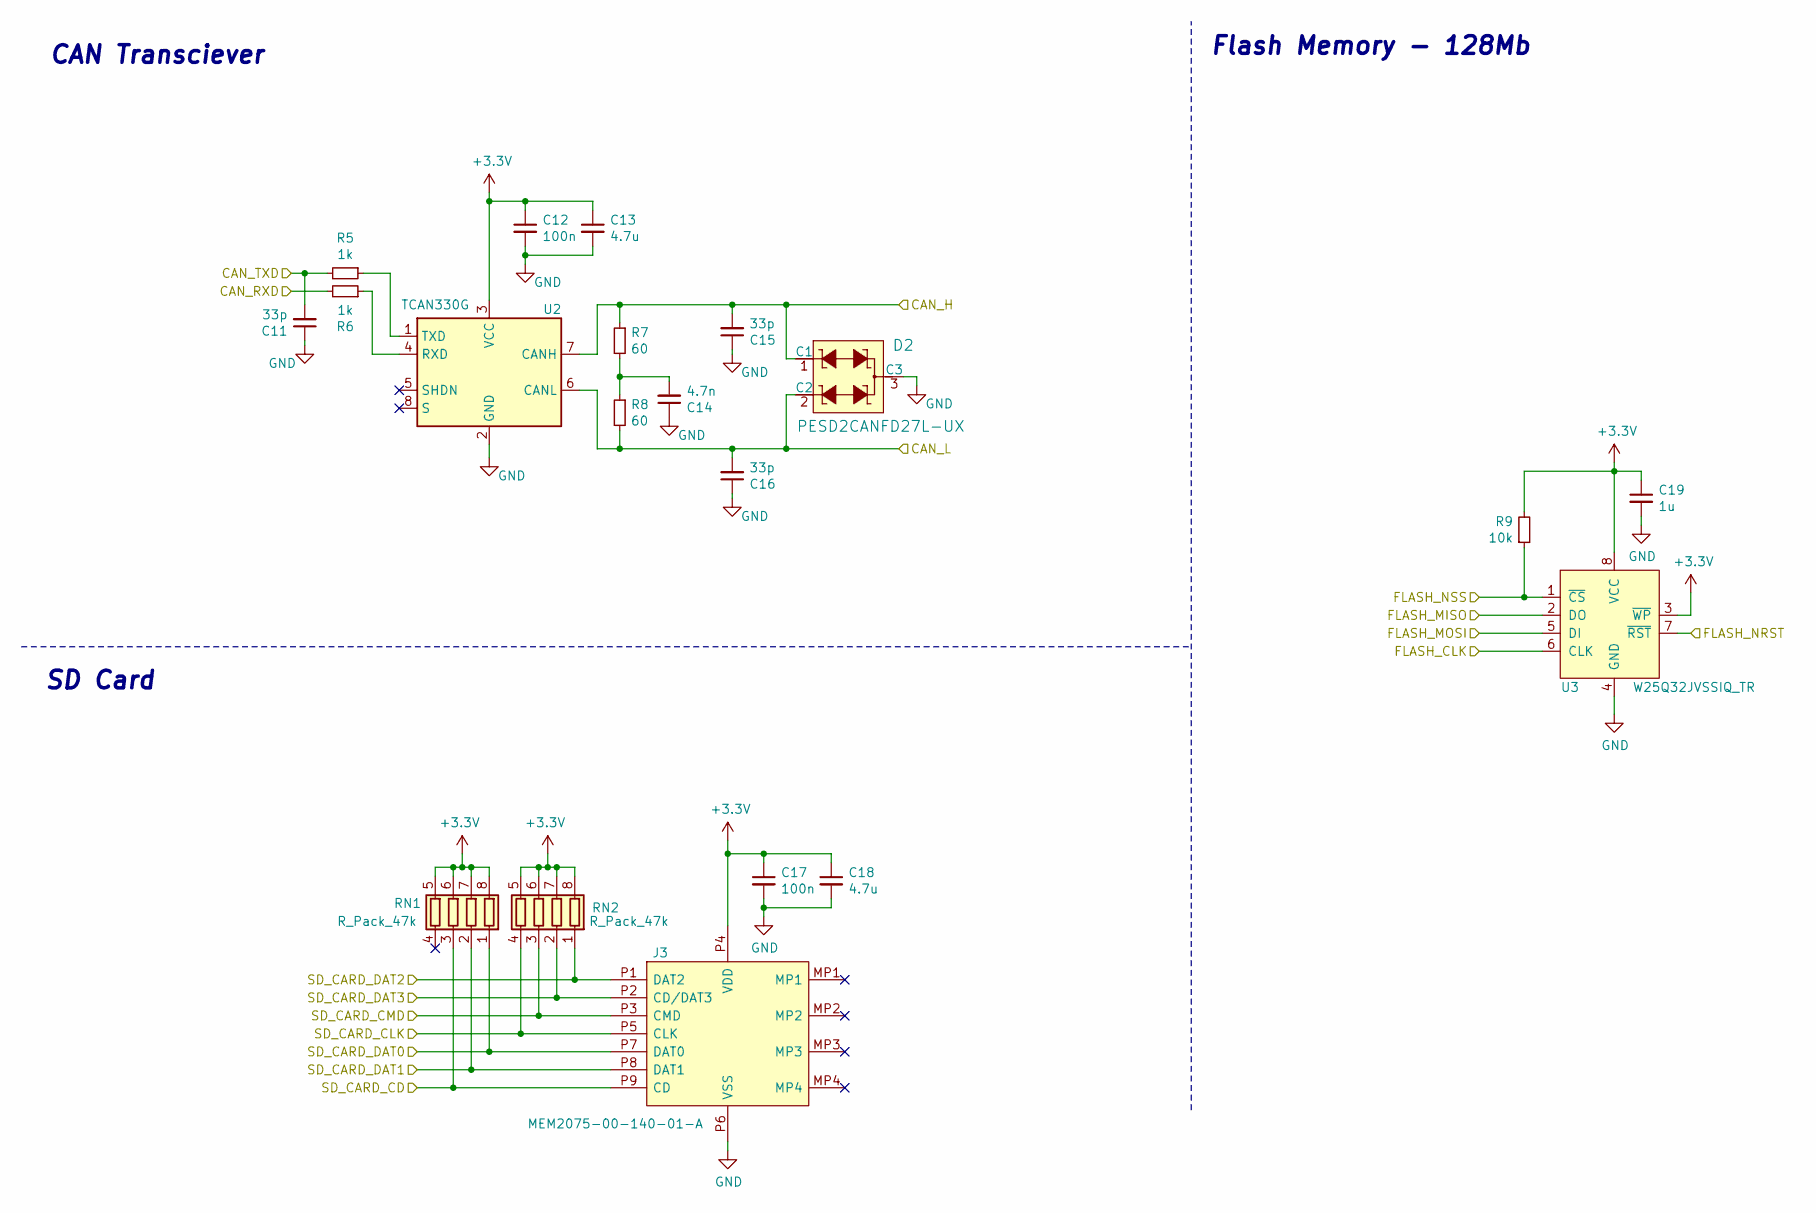
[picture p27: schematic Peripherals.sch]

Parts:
C11, C15, C16: 33p; C_0805_2012Metric
C12, C17: 100n; C_0805_2012Metric
C13, C18: 4.7u; C_0805_2012Metric
C14: 4.7n; C_0805_2012Metric
C19: 1u; C_0805_2012Metric
D2: PESD2CANFD27L-UX; SOT-23-3; MPN PESD2CAN,215; Digi-Key_PN 1727-3891-1-ND
J3: MEM2075-00-140-01-A; MEM20750014001A; Mouser Part Number 640-MEM20750014001A
R5, R6: 1k; R_0805_2012Metric
R7, R8: 60; R_0805_2012Metric
R9: 10k; R_0805_2012Metric
RN1, RN2: R_Pack_47k; YC164JR07220RL
U2: TCAN330G; SOIC-8_3.9x4.9mm_P1.27mm
U3: W25Q32JVSSIQ_TR; SOIC-8_W5.6mm; MPN W25Q32JVSSIQ TR; Digi-Key_PN W25Q32JVSSIQCT-ND

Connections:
3V3: C12.1, C13.1, C17.1, C18.1, C19.1, J3.P4 (VDD), R9.2, RN1.5 (R4.2), RN1.6 (R3.2), RN1.7 (R2.2), RN1.8 (R1.2), RN2.5 (R4.2), RN2.6 (R3.2), RN2.7 (R2.2), RN2.8 (R1.2), U2.3 (VCC), U3.3 (~WP), U3.8 (VCC); also elsewhere on the board
CAN_H: C15.2, D2.1 (C1), R7.1, U2.7 (CANH); also elsewhere on the board
CAN_L: C16.2, D2.2 (C2), R8.2, U2.6 (CANL); also elsewhere on the board
CAN_RX: R6.2; also elsewhere on the board
CAN_TX: C11.2, R5.2; also elsewhere on the board
FLASH_NRST: U3.7 (~RST); also elsewhere on the board
FLASH_NSS: R9.1, U3.1 (~CS); also elsewhere on the board
FLASH_SPI_CLK: U3.6 (CLK); also elsewhere on the board
FLASH_SPI_MISO: U3.2 (DO); also elsewhere on the board
FLASH_SPI_MOSI: U3.5 (DI); also elsewhere on the board
GND: C11.1, C12.2, C13.2, C14.1, C15.1, C16.1, C17.2, C18.2, C19.2, D2.3 (C3), J3.P6 (VSS), U2.2 (GND), U3.4 (GND); also elsewhere on the board
unnamed: C14.2, R7.2, R8.1
unnamed: R5.1, U2.1 (TXD)
unnamed: R6.1, U2.4 (RXD)
SD_CARD_CD: J3.P9 (CD), RN1.3 (R3.1); also elsewhere on the board
SD_CARD_CLK: J3.P5 (CLK), RN2.4 (R4.1); also elsewhere on the board
SD_CARD_CMD: J3.P3 (CMD), RN2.3 (R3.1); also elsewhere on the board
SD_CARD_DAT0: J3.P7 (DAT0), RN1.1 (R1.1); also elsewhere on the board
SD_CARD_DAT1: J3.P8 (DAT1), RN1.2 (R2.1); also elsewhere on the board
SD_CARD_DAT2: J3.P1 (DAT2), RN2.1 (R1.1); also elsewhere on the board
SD_CARD_DAT3: J3.P2 (CD/DAT3), RN2.2 (R2.1); also elsewhere on the board

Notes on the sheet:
CAN Transciever
SD Card
Flash Memory - 128Mb

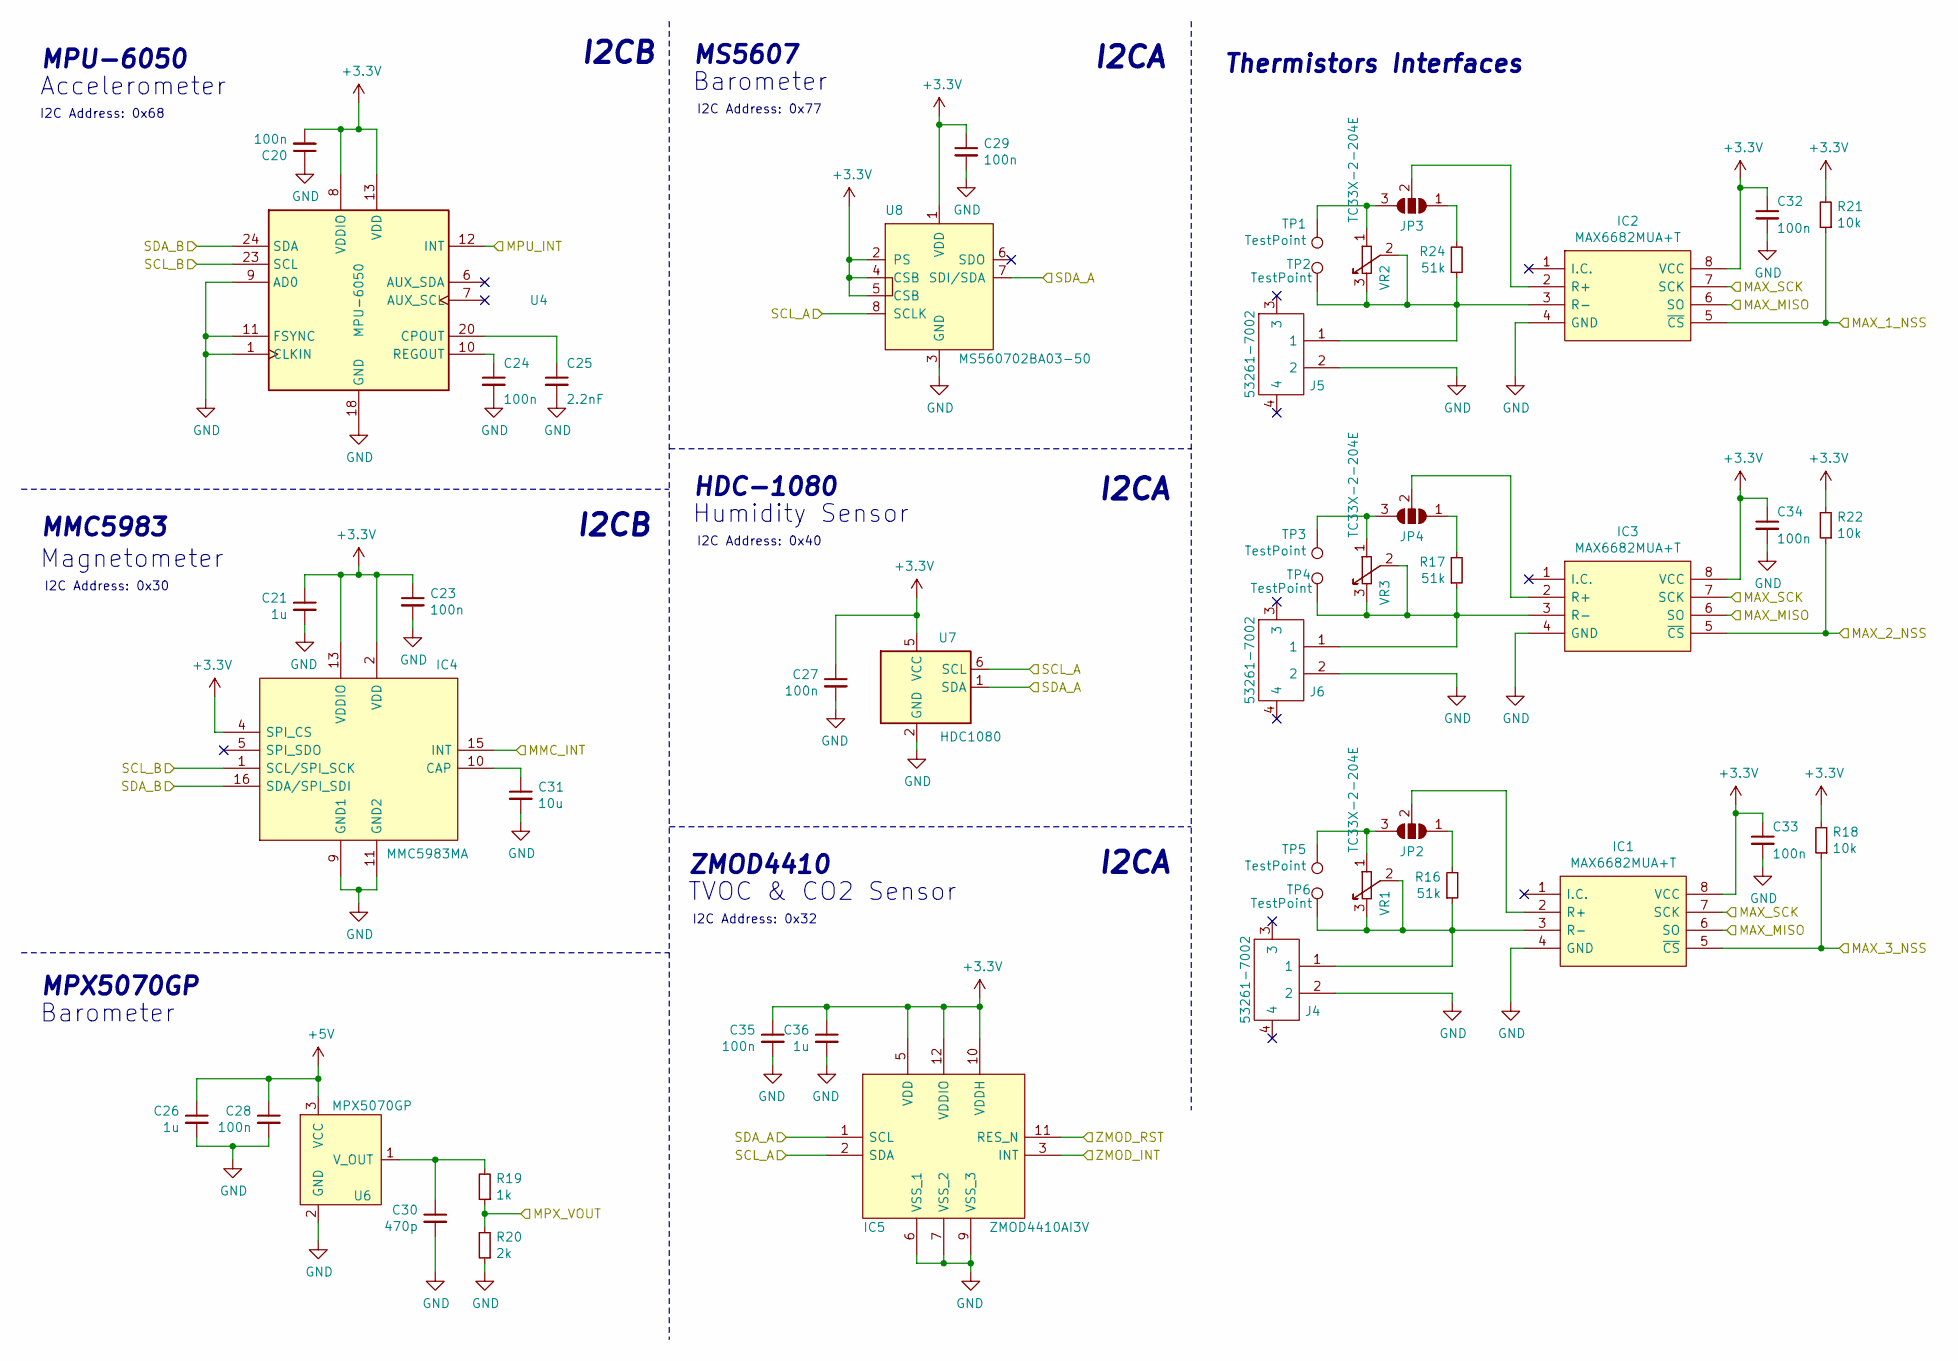
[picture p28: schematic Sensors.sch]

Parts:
C20, C23, C24, C27, C28, C29, C32, C33, C34, C35: 100n; C_0805_2012Metric
C21, C26, C36: 1u; C_0805_2012Metric
C25: 2.2nF; C_0805_2012Metric
C30: 470p; C_0805_2012Metric
C31: 10u; C_0805_2012Metric
IC1, IC2, IC3: MAX6682MUA+T; SOP65P490X110-8N; Mouser Part Number 700-MAX6682MUAT
IC4: MMC5983MA; Mouser Part Number 438-MMC5983MA
IC5: ZMOD4410AI3V; Mouser Part Number 972-ZMOD4410AI3V
J4, J5, J6: 53261-7002; 532617002; Mouser Part Number 538-53261-7002
JP2, JP3, JP4: SolderJumper_3_Open; SolderJumper-3_P1.3mm_Open_RoundedPad1.0x1.5mm_NumberLabels
R16, R17, R24: 51k; R_0805_2012Metric
R18, R21, R22: 10k; R_0805_2012Metric
R19: 1k; R_0805_2012Metric
R20: 2k; R_0805_2012Metric
TP1, TP2, TP3, TP4, TP5, TP6: TestPoint; TestPoint_Pad_D2.0mm
U4: MPU-6050; InvenSense_QFN-24_4x4mm_P0.5mm
U6: MPX5070GP
U7: HDC1080; Texas_PWSON-N6
U8: MS560702BA03-50; SMD-8_5x3mm; MPN MS560702BA03-50; Digi-Key_PN 223-1198-1-ND
VR1, VR2, VR3: TC33X-2-204E; TC33X-2_1; Mouser Part Number 652-TC33X-2-204E

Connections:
3V3: C20.2, C21.1, C23.1, C27.1, C29.1, C32.1, C33.1, C34.1, C35.1, C36.1, IC1.8 (VCC), IC2.8 (VCC), IC3.8 (VCC), IC4.2 (VDD), IC4.4 (SPI_CS), IC4.13 (VDDIO), IC5.5 (VDD), IC5.10 (VDDH), IC5.12 (VDDIO), R18.2, R21.2, R22.2, U4.8 (VDDIO), U4.13 (VDD), U7.5 (VCC), U8.1 (VDD), U8.2 (PS), U8.4 (CSB), U8.5 (CSB); also elsewhere on the board
5V: C26.1, C28.1, U6.3 (VCC); also elsewhere on the board
GND: C20.1, C21.2, C23.2, C24.2, C25.2, C26.2, C27.2, C28.2, C29.2, C30.2, C31.2, C32.2, C33.2, C34.2, C35.2, C36.2, IC1.4 (GND), IC2.4 (GND), IC3.4 (GND), IC4.9 (GND1), IC4.11 (GND2), IC5.6 (VSS_1), IC5.7 (VSS_2), IC5.9 (VSS_3), J4.2, J5.2, J6.2, R20.1, U4.1 (CLKIN), U4.9 (AD0), U4.11 (FSYNC), U4.18 (GND), U6.2 (GND), U7.2 (GND), U8.3 (GND); also elsewhere on the board
MAX_1_NSS: IC2.5 (~CS), R21.1; also elsewhere on the board
MAX_2_NSS: IC3.5 (~CS), R22.1; also elsewhere on the board
MAX_3_NSS: IC1.5 (~CS), R18.1; also elsewhere on the board
MAX_SPI_CLK: IC1.7 (SCK), IC2.7 (SCK), IC3.7 (SCK); also elsewhere on the board
MAX_SPI_MISO: IC1.6 (SO), IC2.6 (SO), IC3.6 (SO); also elsewhere on the board
MMC_INT: IC4.15 (INT); also elsewhere on the board
MPU_INT: U4.12 (INT); also elsewhere on the board
MPX_VOUT: R19.1, R20.2; also elsewhere on the board
unnamed: C24.1, U4.10 (REGOUT)
unnamed: C25.1, U4.20 (CPOUT)
unnamed: C30.1, R19.2, U6.1 (V_OUT)
unnamed: C31.1, IC4.10 (CAP)
unnamed: IC1.2 (R+), JP2.2 (C)
unnamed: IC1.3 (R-), J4.1, R16.1, TP6.1, VR1.2, VR1.3
unnamed: IC2.2 (R+), JP3.2 (C)
unnamed: IC2.3 (R-), J5.1, R24.1, TP2.1, VR2.2, VR2.3
unnamed: IC3.2 (R+), JP4.2 (C)
unnamed: IC3.3 (R-), J6.1, R17.1, TP4.1, VR3.2, VR3.3
unnamed: JP2.1 (A), R16.2
unnamed: JP2.3 (B), TP5.1, VR1.1
unnamed: JP3.1 (A), R24.2
unnamed: JP3.3 (B), TP1.1, VR2.1
unnamed: JP4.1 (A), R17.2
unnamed: JP4.3 (B), TP3.1, VR3.1
SCL_A: IC5.2 (SDA), U7.6 (SCL), U8.8 (SCLK); also elsewhere on the board
SCL_B: IC4.1 (SCL/SPI_SCK), U4.23 (SCL); also elsewhere on the board
SDA_A: IC5.1 (SCL), U7.1 (SDA), U8.7 (SDI/SDA); also elsewhere on the board
SDA_B: IC4.16 (SDA/SPI_SDI), U4.24 (SDA); also elsewhere on the board
ZMOD_INT: IC5.3 (INT); also elsewhere on the board
ZMOD_RST: IC5.11 (RES_N); also elsewhere on the board

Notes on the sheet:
Thermistors Interfaces
MPU-6050
MS5607
MMC5983
HDC-1080
Humidity Sensor
Magnetometer
Accelerometer
Barometer
MPX5070GP
I2C Address: 0x77
I2C Address: 0x40
I2C Address: 0x68
I2C Address: 0x30
ZMOD4410
TVOC & CO2 Sensor
I2C Address: 0x32
I2CA
I2CB

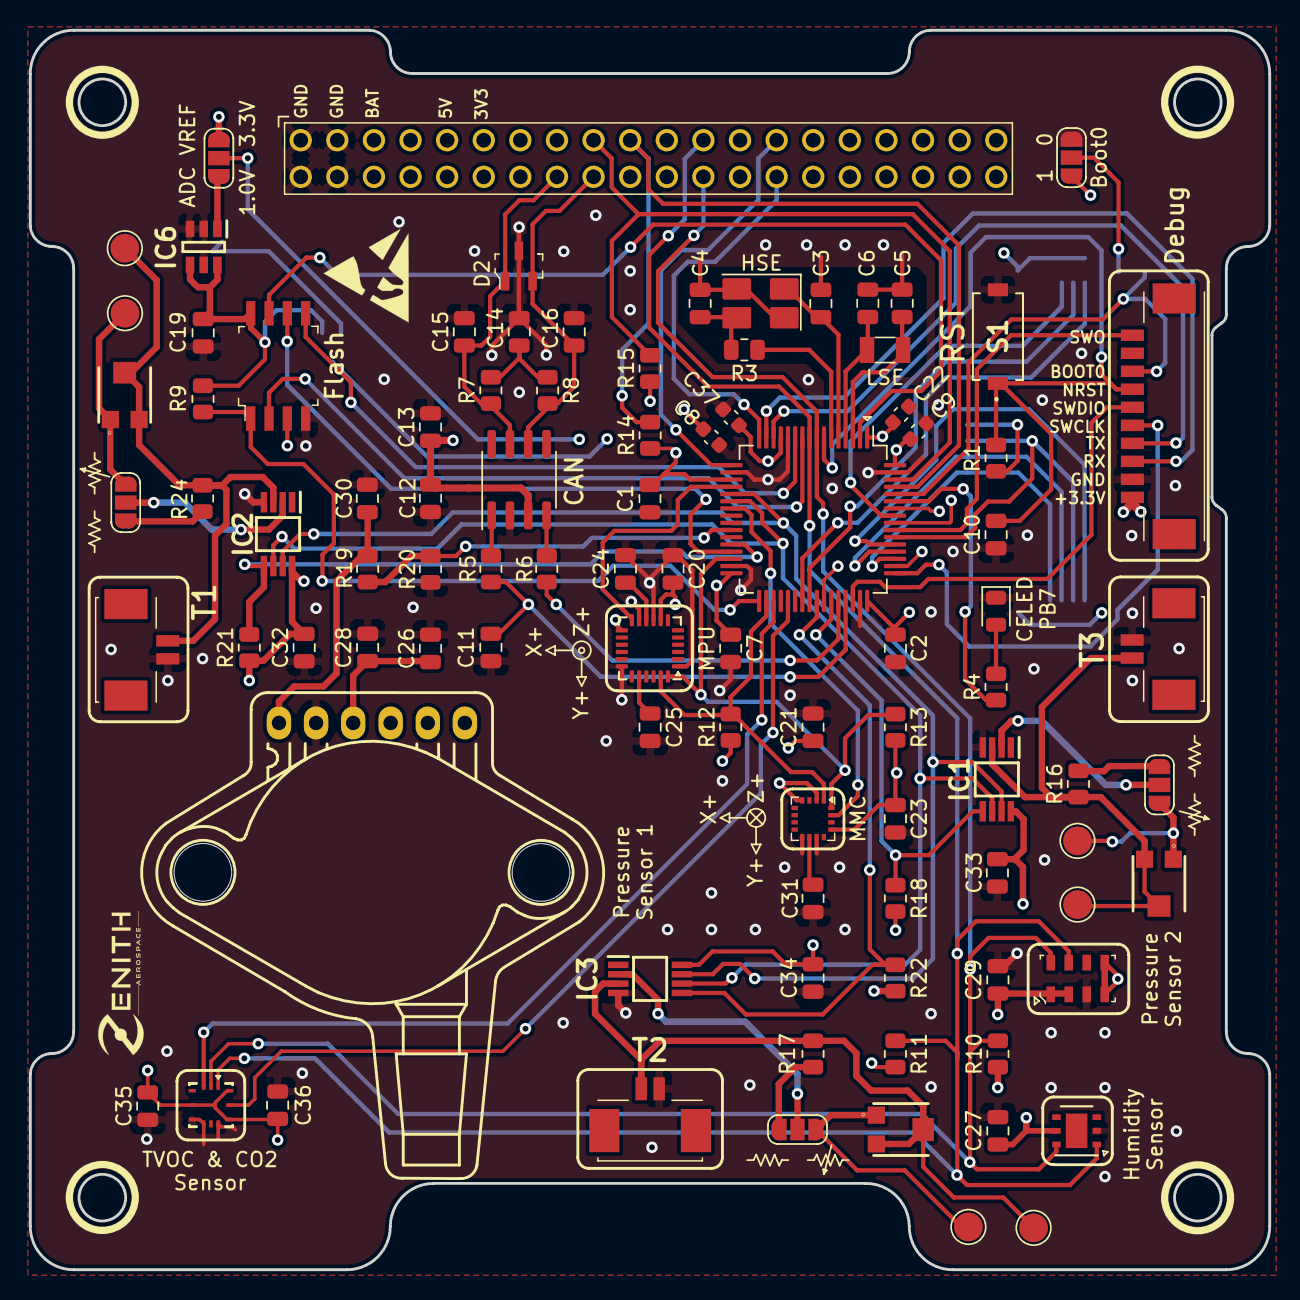
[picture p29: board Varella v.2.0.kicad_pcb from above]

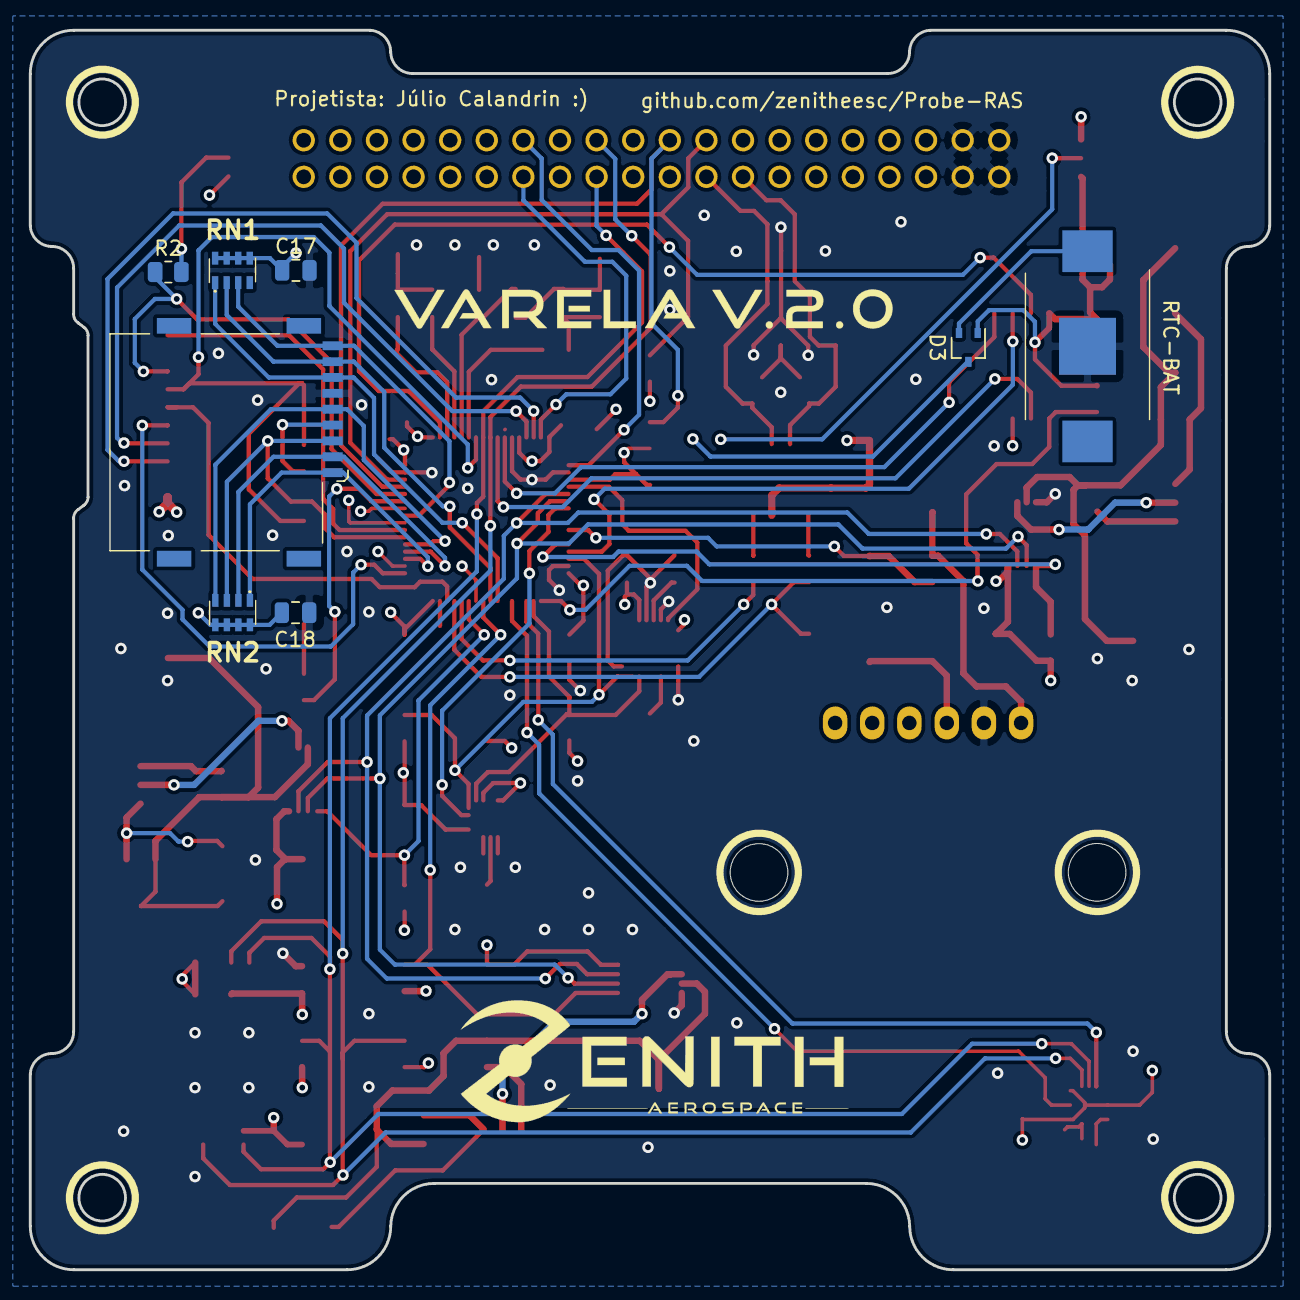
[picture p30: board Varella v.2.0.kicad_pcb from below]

Board: 4 copper layers, 86.0 x 86.0 mm, 102 parts (8 on the bottom side), 79 nets.

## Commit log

2022-01-19 Add Board
    [BottomLayerComponents.dxf, Peripherals.sch, Sensors.sch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]
2022-01-20 Add shapes3D folder
    Now all 3D models for the components are stored in a single folder, thanks to the Archive Plugin from https://github.com/MitjaNemec/Kicad_action_plugins.git
    [532610271 recolored.step, 532611071 recolored.step, C_0805_2012Metric.step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]
2022-01-20 Revert "Add shapes3D folder"
    This reverts commit 1c3042b7a1c052b8553a455bf3bd885d3494e48a.
    [532610271 recolored.step, 532611071 recolored.step, C_0805_2012Metric.step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]
2022-01-20 Add shapes3D folder again
    Something went wrong on the last commit. The hierarchical sheets had been corrupted after the archiving process, so I reverted the commit and did the procedure again. Everything appears to be working this time.
    [532610271 recolored.step, 532611071 recolored.step, C_0805_2012Metric.step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]
2022-01-20 Revert "Add shapes3D folder again"
    This reverts commit 7987a310af828f940c17547aa6162ac2ebe2b018.
    [532610271 recolored.step, 532611071 recolored.step, C_0805_2012Metric.step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]
2022-01-20 Archive project
    [532610271 recolored.step, 532611071 recolored.step, C_0805_2012Metric.step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]
2022-01-20 Update Archive
    [Varella v.2.0.kicad_pcb]
2022-01-20 Archive Schematic
    [Peripherals.sch, Sensors.sch, Varella v.2.0.sch]
2022-01-27 Add Traces to Stack Connector
    Connects the Interrupts and PWM pins that come from the EPS boards through the Stack Connector to Varella's STM32.
    [Varella v.2.0.kicad_pcb, Varella v.2.0.sch]
2022-01-27 Add BOM and update image of the first page
    [Varella v.2.0.kicad_pcb]
2022-02-03 Correct diagram component name
    MAX6682 replaced the MAX31856 during development, but the diagram was never updated.
    [Varella v.2.0.kicad_pcb]
2022-02-05 Update RTC Battery Silk Screen name
    [Varella v.2.0.kicad_pcb, Varella v.2.0.sch]
2022-02-09 Add 1,024 V voltage reference for the ADC.
    We realised that the MPX5700 barometer would only output a voltage from 0 to 0,66 V in the altitude range of the radiosonde trajectory. By adding this voltage reference to the ADC we will have much b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
    [Varella v.2.0.kicad_pcb, Varella v.2.0.sch]
2022-06-09 Reroutes voltage reference selector trace for better aesthetics.
    [Peripherals.sch, Varella v.2.0.kicad_pcb]
2022-07-14 Change silkscreen
    Adds the name "Varela" to the board.
    Also adds the name of the designer (me).
    [Varella v.2.0.kicad_pcb]

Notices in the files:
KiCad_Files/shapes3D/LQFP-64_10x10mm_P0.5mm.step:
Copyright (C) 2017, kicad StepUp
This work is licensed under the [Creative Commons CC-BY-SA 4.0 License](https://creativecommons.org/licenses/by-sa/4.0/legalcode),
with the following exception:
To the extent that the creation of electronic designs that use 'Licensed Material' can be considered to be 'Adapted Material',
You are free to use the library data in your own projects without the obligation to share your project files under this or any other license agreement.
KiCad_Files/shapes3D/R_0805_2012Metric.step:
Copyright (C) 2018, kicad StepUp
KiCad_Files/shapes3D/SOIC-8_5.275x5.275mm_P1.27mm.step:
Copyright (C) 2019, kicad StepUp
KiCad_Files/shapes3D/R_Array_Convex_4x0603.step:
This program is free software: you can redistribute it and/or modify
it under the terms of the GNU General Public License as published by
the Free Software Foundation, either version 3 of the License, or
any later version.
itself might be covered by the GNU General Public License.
